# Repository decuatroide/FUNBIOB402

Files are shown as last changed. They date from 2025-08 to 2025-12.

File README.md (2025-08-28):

# Fundamentos de Biodiseño – Grupo 09 
<p align="center">
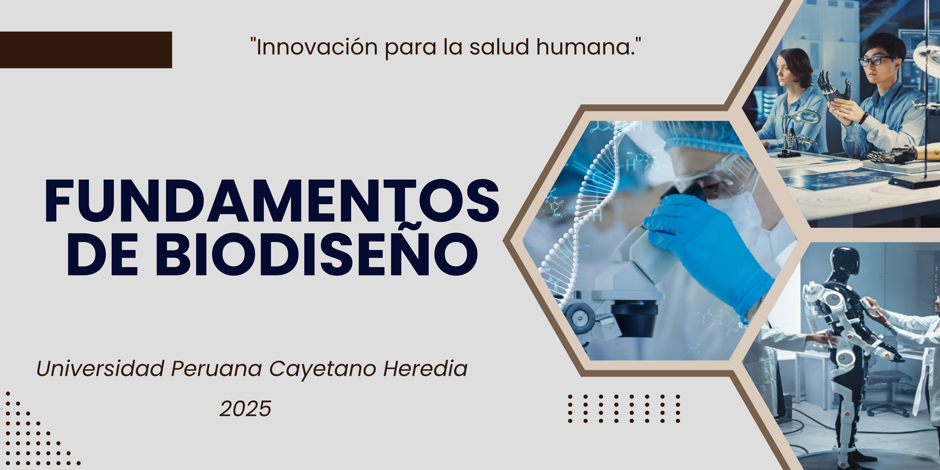
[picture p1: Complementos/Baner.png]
Banner Grupo 09
  
</p>

<p align="center">
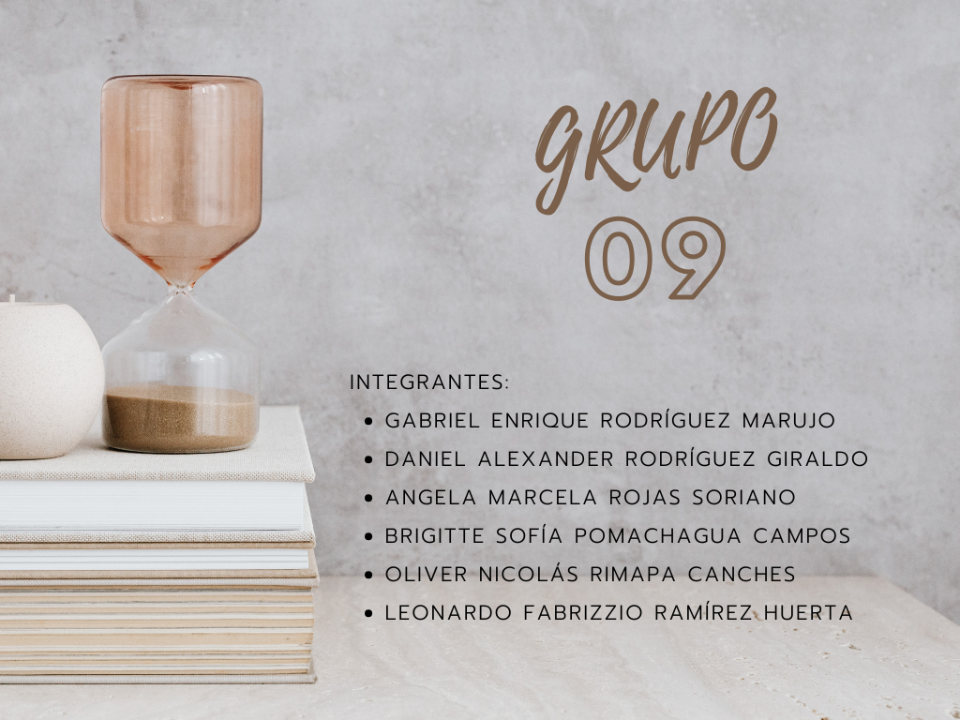
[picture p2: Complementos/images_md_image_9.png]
Carátula del grupo
  
</p>

📸 **Foto de Grupo** 
<p align="center">
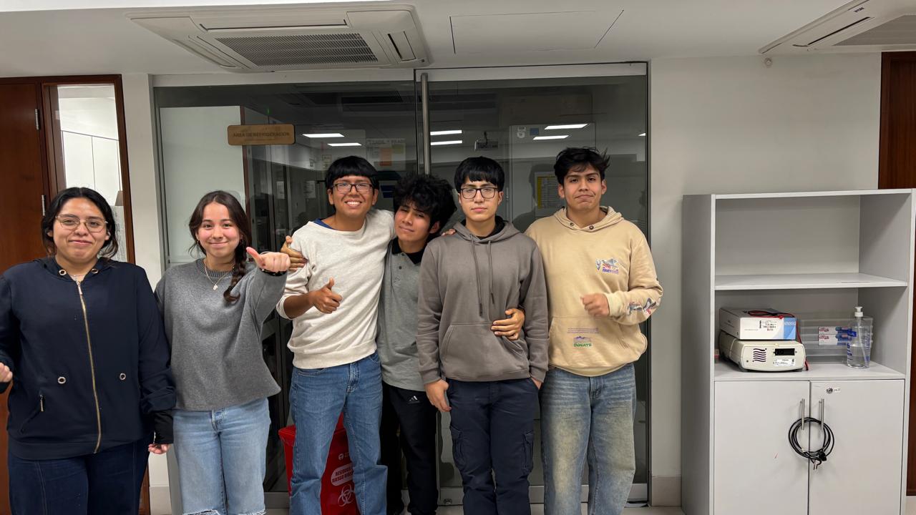
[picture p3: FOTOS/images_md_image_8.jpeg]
Foto de grupo
  
</p>

👩‍🔬**Sobre nosotros**

Somos el Grupo 09 de Fundamentos de Biodiseño, conformado por estudiantes universitarios comprometidos con el aprendizaje y la innovación.  

> 🎯 **Misión:** Integrar los conocimientos de ciencias básicas y diseño con una mirada **creativa y crítica**.  
> 🌍 **Visión:** Proponer **soluciones sostenibles** a los retos que enfrenta la salud y la sociedad actual.  
> 💡 **Objetivo:** Aprender, aplicar y **crear impacto real** mediante el biodiseño.

📚 **Durante el curso buscamos** 

- 🧠 *Adquirir bases teóricas sólidas* .  
- 🤝 *Desarrollar habilidades de trabajo en equipo, análisis y aplicación práctica*.  
- 🚀 *Formarnos como profesionales preparados para afrontar los futuros desafíos de la ingeniería biomédica** .
  
👥 **Integrantes**   
</div>
<table>
  <tr>
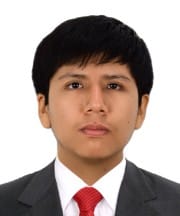
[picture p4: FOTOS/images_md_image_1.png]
    <td width="150px"></td>
    <td>
      <b>Gabriel Enrique Rodríguez Marujo</b>  
      <br>Edad: 18 años  
      <br>🏀 Hábito: Jugar básquet  
      <br><i>"Espero aprender a analizar diferentes tipos de problemáticas y emplear nuevas metodologías y herramientas para llegar a una solución."</i>  
      <br><b>Rol:</b> <font color="blue">Lider </font>
    </td>
  </tr>
</table>

---

<table>
  <tr>
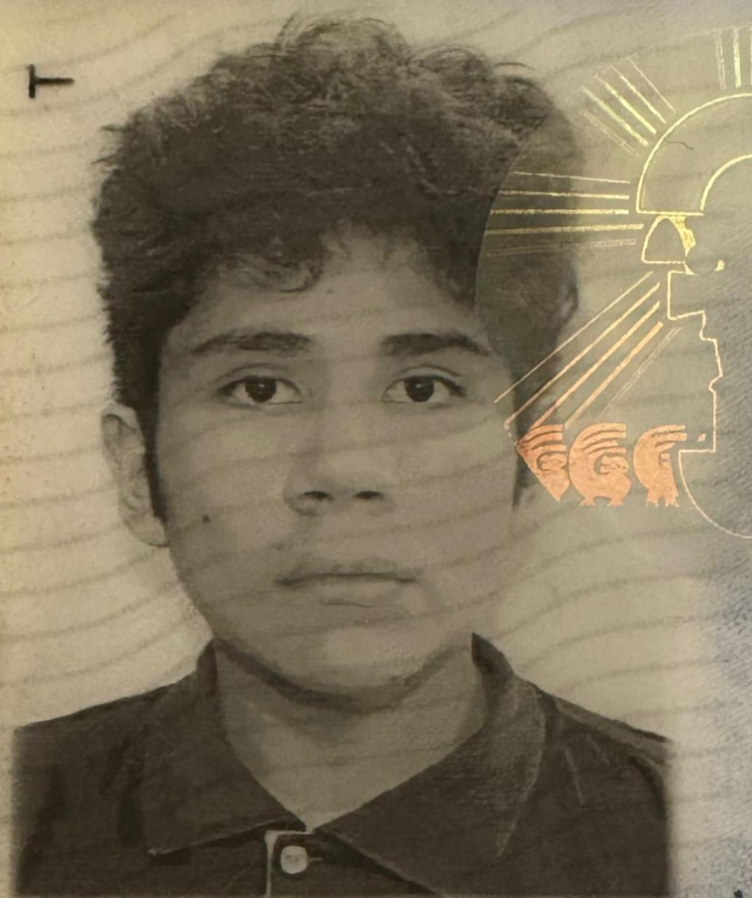
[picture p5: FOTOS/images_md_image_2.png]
    <td width="150px"></td>
    <td>
      <b>Daniel Alexander Rodríguez Giraldo</b>  
      <br>Edad: 19 años  
      <br>🤝 Hábito: Jugar con mis amigos  
      <br><i>"Espero poder aprender mucho en este curso ya que es afín a nuestra carrera."</i>  
      <br><b>Rol:</b> <font color="green">Secretario</font>
    </td>
  </tr>
</table>

---

<table>
  <tr>
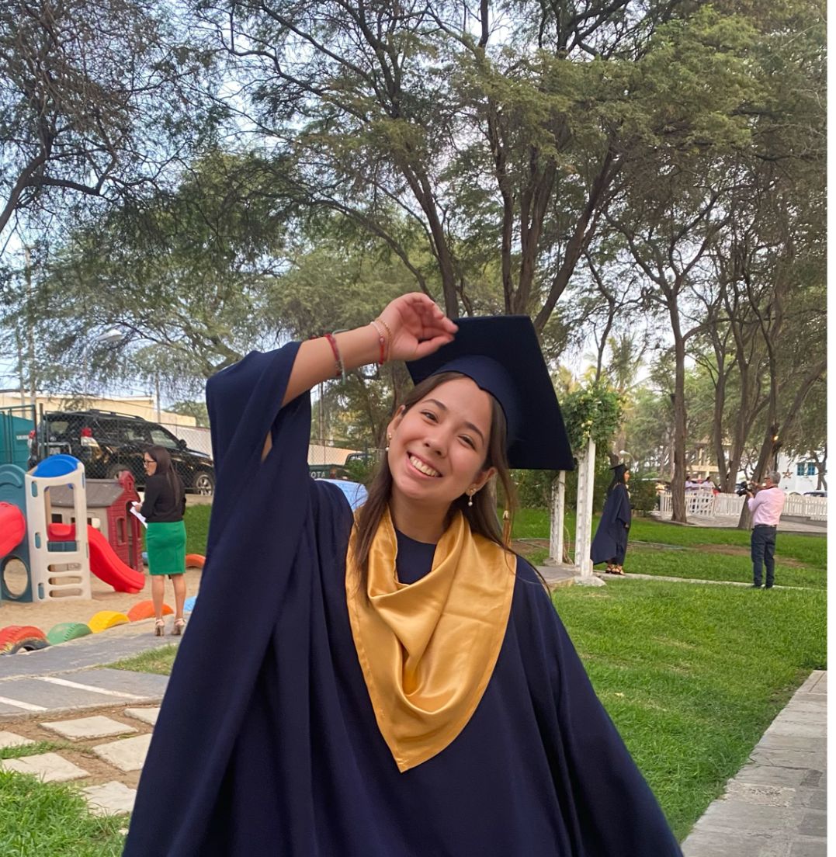
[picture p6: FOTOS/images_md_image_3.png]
    <td width="150px"></td>
    <td>
      <b>Angela Marcela Rojas Soriano</b>  
      <br>Edad: 18 años  
      <br>✈️📸 Hábito: Viajar y tomar fotos  
      <br><i>"Espero aprovechar al máximo las herramientas que este curso ofrece para usarlas en el futuro de mi desarrollo profesional como ingeniera biomédica."</i>  
      <br><b>Rol:</b> <font color="purple">Diseño</font>
    </td>
  </tr>
</table>

---

<table>
  <tr>
    <td width="150px"></td>
    <td>
      <b>Brigitte Sofía Pomachagua Campos</b>  
      <br>Edad: 18 años  
      <br>🎬🍿 Hábito: Ver series y películas  
      <br><i>"Deseo adquirir experiencia en biodiseño para futuros proyectos profesionales."</i>  
      <br><b>Rol:</b> <font color="red">Documentación</font>
    </td>
  </tr>
</table>

---

<table>
  <tr>
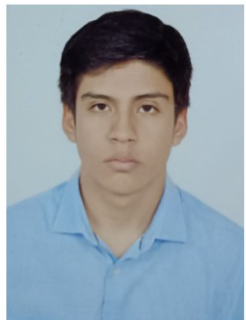
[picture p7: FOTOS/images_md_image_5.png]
    <td width="150px"></td>
    <td>
      <b>Oliver Nicolás Rimapa Canches</b>  
      <br>Edad: 18 años  
      <br>📚📖 Hábito: Leer libros e historietas  
      <br><i>"Espero aportar ideas innovadoras y aprender de mis compañeros."</i>  
      <br><b>Rol:</b> <font color="orange">Organización</font>
    </td>
  </tr>
</table>

---

<table>
  <tr>
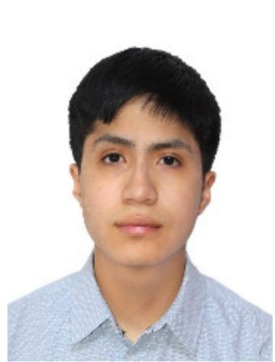
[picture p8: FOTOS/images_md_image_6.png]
    <td width="150px"></td>
    <td>
      <b>Leonardo Fabrizzio Ramírez Huerta</b>  
      <br>Edad: 18 años  
      <br>🎨 Hábito: Dibujo  
      <br><i>"Deseo adquirir experiencia en biodiseño para futuros proyectos profesionales."</i>  
      <br><b>Rol:</b> <font color="brown">Logistica</font>
    </td>
  </tr>
</table>

✨ **Compromiso del Grupo** 

*Estamos convencidos de que la innovación nace del trabajo colaborativo.*  
*Nuestro reto es diseñar soluciones creativas que mejoren la salud y la calidad de vida.* 

*Grupo 09 – Fundamentos de Biodiseño*        📍 *Universidad Peruana Cayetano Heredia – 2025*

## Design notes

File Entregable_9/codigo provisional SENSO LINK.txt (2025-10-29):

// === Pines sensores ===
#define TRIG_FRONT  4
#define ECHO_FRONT  5
#define TRIG_BACK   18
#define ECHO_BACK   19
#define TRIG_LEFT   21
#define ECHO_LEFT   22
#define TRIG_RIGHT  25
#define ECHO_RIGHT  26

// === Pin del módulo de vibración (elige un GPIO de salida) ===
#define PIN_VIB     23   // cambia a tu GPIO "MODVIB" real (evita 34–39)

// === Constantes ===
#define SOUND_SPEED   0.034   // cm/us
#define OBSTACLE_LIMIT 20     // cm
#define INTER_PING_MS  70     // separación entre sensores para evitar diafonía

float medirDistancia(int trigPin, int echoPin) {
  digitalWrite(trigPin, LOW);
  delayMicroseconds(2);
  digitalWrite(trigPin, HIGH);
  delayMicroseconds(10);
  digitalWrite(trigPin, LOW);

  long duracion = pulseIn(echoPin, HIGH, 30000); // 30 ms
  if (duracion == 0) return 400.0;               // timeout => fuera de rango
  float distancia = duracion * SOUND_SPEED * 0.5;
  if (distancia > 400) distancia = 400;
  return distancia;
}

void setup() {
  Serial.begin(115200);

  pinMode(TRIG_FRONT, OUTPUT);  pinMode(ECHO_FRONT, INPUT);
  pinMode(TRIG_BACK,  OUTPUT);  pinMode(ECHO_BACK,  INPUT);
  pinMode(TRIG_LEFT,  OUTPUT);  pinMode(ECHO_LEFT,  INPUT);
  pinMode(TRIG_RIGHT, OUTPUT);  pinMode(ECHO_RIGHT, INPUT);

  pinMode(PIN_VIB, OUTPUT);
  digitalWrite(PIN_VIB, LOW);

  Serial.println("=== Sistema de detección de obstáculos iniciado ===");
}

void loop() {
  float dFront = medirDistancia(TRIG_FRONT, ECHO_FRONT);
  delay(INTER_PING_MS);
  float dBack  = medirDistancia(TRIG_BACK,  ECHO_BACK);
  delay(INTER_PING_MS);
  float dLeft  = medirDistancia(TRIG_LEFT,  ECHO_LEFT);
  delay(INTER_PING_MS);
  float dRight = medirDistancia(TRIG_RIGHT, ECHO_RIGHT);

  Serial.println("------ Lecturas de sensores (cm) ------");
  Serial.print("Frente: ");   Serial.print(dFront); Serial.print(" cm\t");
  Serial.print("Atras: ");    Serial.print(dBack);  Serial.println(" cm");
  Serial.print("Izquierda: ");Serial.print(dLeft);  Serial.print(" cm\t");
  Serial.print("Derecha: ");  Serial.print(dRight); Serial.println(" cm");
  Serial.println("---------------------------------------");

  bool peligro = (dFront < OBSTACLE_LIMIT) || (dBack < OBSTACLE_LIMIT) ||
                 (dLeft  < OBSTACLE_LIMIT) || (dRight< OBSTACLE_LIMIT);

  // Alerta (ON/OFF simple). Si tu driver admite PWM, puedo pasarlo a ledc.
  digitalWrite(PIN_VIB, peligro ? HIGH : LOW);

  if (dFront < OBSTACLE_LIMIT)  Serial.println("⚠  Obstáculo al FRENTE");
  if (dBack  < OBSTACLE_LIMIT)  Serial.println("⚠  Obstáculo ATRÁS");
  if (dLeft  < OBSTACLE_LIMIT)  Serial.println("⚠  Obstáculo a la IZQUIERDA");
  if (dRight < OBSTACLE_LIMIT)  Serial.println("⚠  Obstáculo a la DERECHA");
  if (!peligro)                 Serial.println("✅  Zona despejada.");

  Serial.println();
  delay(200);
}

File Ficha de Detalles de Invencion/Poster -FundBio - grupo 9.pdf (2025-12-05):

# SENSO LINK - SISTEMA INTEGRADO DE BASTÓN CON SENSORES Y APLICACIÓN PARA PERSONA CON SÍNDROME DE CHARGE CON PROBLEMAS SENSORIALES

## Analisis del caso/problematica

## Requerimientos de diseño

## Diseño/Prototipado

## Conclusiones y recomendaciones

### Daniel Rodriguez, Leonardo Ramirez, Oliver Rimapa y Gabriel Rodriguez Marujo

1

### Fundamentos de Biodiseño 2025-2, Ingeniería Biomedica, Facultad de Ciencias e Ingenieria

Paciente:

Piero Franco Zapata, varón de 23 años, diagnosticado con Síndrome CHARGE, una enfermedad genética multisistémica de baja prevalencia (≈1:10000 nacidos vivos), asociada principalmente a mutaciones del gen CHD7 localizado en el cromosoma 8q12.2. [1]

Diagnóstico:

- Síndrome CHARGE: colobomas oculares bilaterales, ceguera total (OI) y baja visión (OD).
- Hipoacusia neurosensorial bilateral: (moderada OD, severa OI).
- Cirugía de escoliosis dorsolumbar (D3–L4): rigidez postural y fatiga.
- Déficit vestibular: dificultad de equilibrio.
- Estado actual: clínicamente estable, pero con dependencia sensorial y emocional al desplazarse solo.

Principal frustración: “No puedo ver correctamente”.

[1] National Eye Institute (NEI), “Coloboma,” National Institutes of Health, Bethesda, MD, 2025. [Online]. Available: https://www.nei.nih.gov/espanol/aprenda-sobre-la-salud-ocular/enfermedades-y-afecciones-de-los-ojos/coloboma.
[2] Google Images, “Hipoacusia neurosensorial bilateral,” Google LLC, Mountain View, CA, 2025. [Online]. Available: https://www.google.com/search?q=hipoacusia+neurosensorial+bilateral+imagen.
[3] Top Doctors, “Déficit vestibular – Reeducación vestibular,” Top Doctors SL, Spain, 2025. [Online]. Available: https://www.topdoctors.es/articulos-medicos/la-reeducacion-vestibular-vertigo-e-inestabilidad/.

[4]World Health Organization (WHO), “Blindness and Visual Impairment – Fact Sheet,” World Health Organization, Geneva, 2024. [Online]. Available: https://www.who.int/es/news-room/fact-sheets/detail/blindness-and-visual-impairment

[5]Consejo Nacional para la Integración de la Persona con Discapacidad (CONADIS), “Se registran 801 mil personas con discapacidad visual en todo el Perú,” Gobierno del Perú, 2024. [Online]. Available: https://www.gob.pe/institucion/conadis/noticias/22052-se-registran-801-mil-personas-con-discapacidad-visual-en-todo-el-peru

## Objetivos

## Resultados y Discusión

## EQUIPO 9 / B-402

Necesidad identificada: “Falta de capacidad sensorial para realizar actividades cotidianas fuera de casa, especialmente derivada de su discapacidad visual y auditiva combinada.”

Objetivo: Diseñar un prototipo que se adapte a las herramientas que ya usa (bastón) para que se sienta más seguro al momento de desplazarse por la calle y su universidad.

Funcionales (F):

1. Detección de obstáculos en rango cercano (0.2 m a 3 m).
2. Retroalimentación háptica direccional según proximidad/dirección del obstáculo.
3. Sincronización | bastón–sistema | integrado | - | App: | mediante
comunicación inalámbrica (p. ej. Bluetooth).
4. Modo bajo consumo de energía para prolongar autonomía.
5. Calibración del usuario (ajuste de sensibilidad, zonas de vibración).

No funcionales (NF):

1. Peso máximo: < 500 g adicionales (bastón + sistema integrado).
2. Tiempo de respuesta: latencia < 100 ms.
3. Durabilidad: resistente a impactos leves, uso diario.
4. Facilidad de uso: interfaz mínima, intuitiva.
5. Costo objetivo: menor que tecnologías altas (e.g. < US$ 500).

Solución: SENSO-LINK

Sistema de navegación táctil con sensores ultrasónicos integrados al bastón.

¿Cómo funciona?

- Usa 4 sensores, el primera con dirección hacia abajo el cual mide la distancia de SENSO-LINK al suelo y esta medida, activa a los otros sensores(1 frontal,2 laterales) para que detecten los obstáculos)
- La información se procesa en tiempo real con un microcontrolador.
- Un módulo vibrador alerta a Piero con patrones táctiles intuitivos según la dirección del obstáculo.

Pasos:

1.- Hardware: (Componentes electrónicos) 2.- Software: (Aplicación - Botón de pánico)

3.- Manufactura Digital: (Case)

4.- | Ensamblado:

Limitaciónes:

}

Posibles Mejoras:
- Sensores de mayor área
- Case adaptable a diferentes tamaños
- Mayor duración de la batería
- Aplicación sin restricción a la hora de enviar SMS
- Boton de mayor presencia
- Case más compacto y estético

En conclusión, nuestro prototipo tiene bien definido el objetivo de ser un sistema integrado que se pueda adaptar a cualquier tipo de bastón para personas con problemas sensoriales similares a nuestro caso clínico debido a su bajo peso, poco espacio y que aprovecha las herramientas de los pacientes para cumplir su función. Sin embargo, aún tiene fuertes limitaciones que pueden ser resueltas que comprometen a los objetivos principales con un poco más de presupuesto y tiempo para que pueda llegar a ser totalmente funcional.

1er Case
2do Case
Duración de la batería | Entre 2 a 3h vibrando constantemente y unas 4 si no llega a detectar nada por grandes periodos de tiempo
Visión limitada | Por el mismo planteamiento solo compara el terreno en 3 direcciones, a futuro con sensores de mayor rango se espera poder abarcar un mayor rango
El botón de emergencia aún requiere participación del paciente | El SMS aún no se envia automaticamente
Aún ocupa mucho espacio | Por el planteamiento actual del proyecto no es posible reducir su tamaño pero se espera volverlo un aditamento discreto para cualquier bastón

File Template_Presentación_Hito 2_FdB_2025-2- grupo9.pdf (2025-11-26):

# Indicaciones

- Este template es un esquema base para la construcción de su Elevator Pitch en base a los entregables del curso.
- Se recomienda hacer una presentación con alto contenido visual, enfocada en presentar ideas centrales en un Pitch de 7 minutos.
- El diseño estético de la carátula y de las demás diapositivas queda a criterio del alumno. El orden y contenido indicado en cada slide es obligatorio.

# - Se recomienda ceñirse al número de slides del template, para utilizar aproximadamente 1

min/diapositiva y culminar en el tiempo asignado. Sean precisos y claros en su discurso.
- El slide para la demo está fuera de los 7 min y puede durar 2:00 min máx. Los slides extra son para información de soporte durante las preguntas de los asesores respecto a los retos y limitaciones de sus prototipos.
- Asistir con vestimenta formal para la presentación del Hito N° 2.

# ¡Éxitos en su presentación!

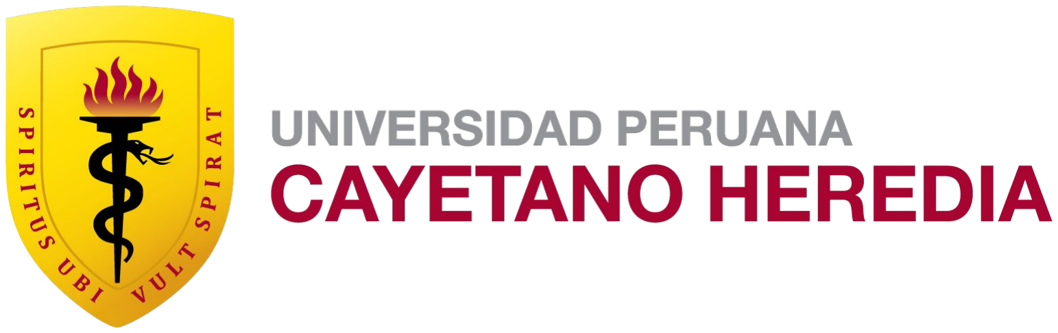
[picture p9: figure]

# SENSO-LINK

# SENSO-LINK

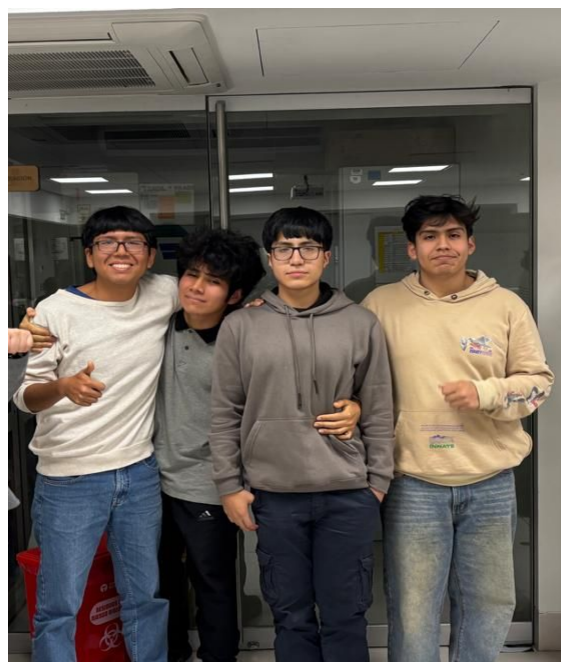
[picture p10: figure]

# Integrantes del grupo 9: - Daniel Alexander Rodríguez Giraldo - Oliver Nicolás Rimapa Canches - Leonardo Fabrizzio Ramírez Huerta - Gabriel Enrique Rodriguez Marujo

# - Leonardo Fabrizzio Ramírez Huerta - Gabriel Enrique Rodriguez Marujo

# Problemática

# Paciente: Piero Franco Zapata diagnosticado con

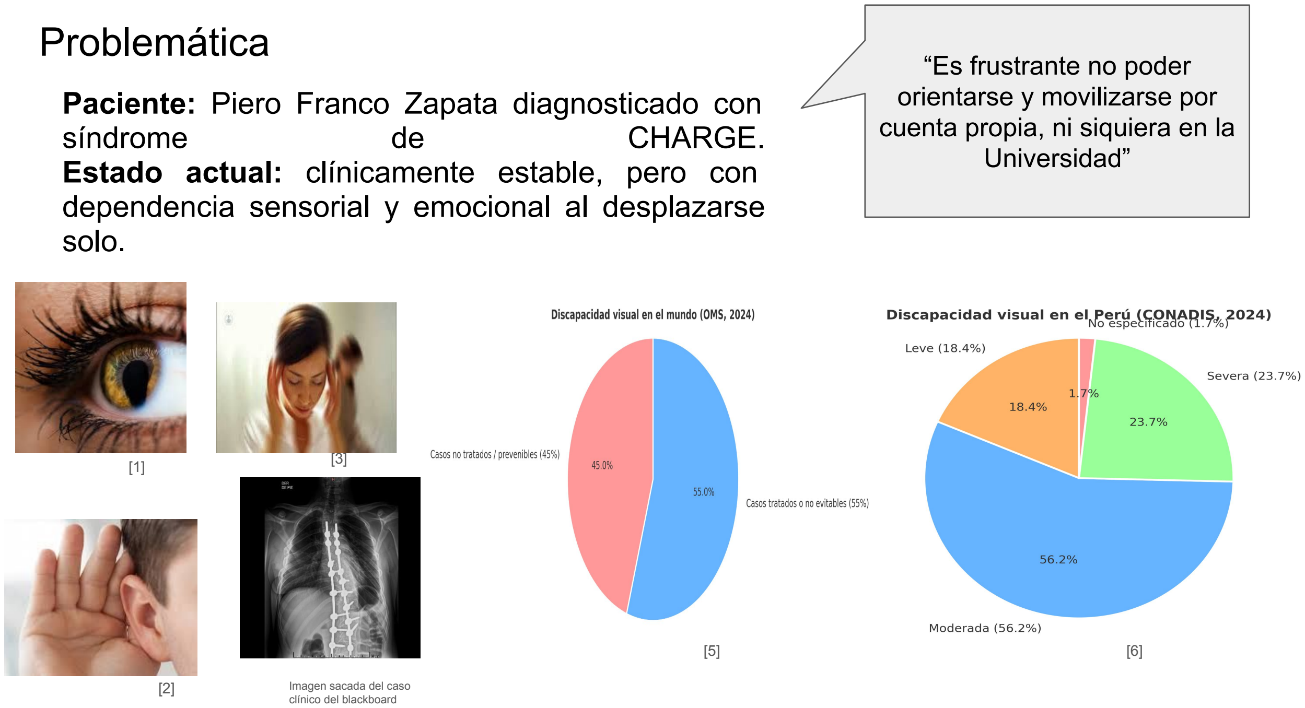
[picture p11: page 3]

síndrome | de | CHARGE.

# Estado actual: clínicamente estable, pero con dependencia sensorial y emocional al desplazarse

solo.

# “Es frustrante no poder orientarse y movilizarse por cuenta propia, ni siquiera en la Universidad”

Imagen sacada del caso
clínico del blackboard

[1]

[2]

[3]

[5] [6]

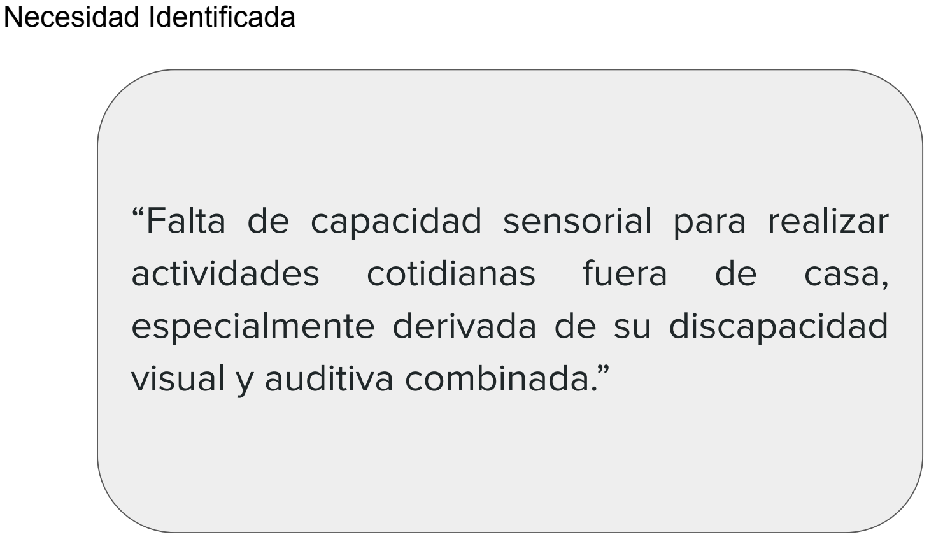
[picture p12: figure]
actividades; cotidianas; fuera; casa,; visual y auditiva combinada.”; Necesidad Identificada

# “Falta de capacidad sensorial para realizar

# especialmente derivada de su discapacidad

# Estado del Arte: Inspiraciones tecnológicas para nuestro prototipo

Patente | Dispositivo | Aporte clave | Aplicación
US12133582B1 [6] | Gafas hápticas | Sistema multisensorial para identificar obstáculos cercanos | Referencia para optimizar la lectura y activación de los sensores ultrasónicos
US20210369545A1 [7] | Bastón inteligente | Algoritmo que combina datos de sensores para alertas más precisas | Inspiración para mejorar la precisión de detección del bastón.
WO2022131891A1 [8] | Bastón háptico | Emisión de vibración. | Referente para implementar vibraciones direccionales en el bastón
US10900788B2 [9] | Cinturón sensorial | Activación de una señal de emergencia según activación del usuario. | Inspiración para el botón de pánico que envía SMS a un familiar cercano

# Solución

# SENSO-LINK

Sistema de navegación táctil con sensores ultrasónicos integrados al bastón.

# ¿Cómo funciona? (3 pasos)

- Usa 4 sensores, el primera con dirección hacia abajo el cual mide la distancia de SENSO-LINK al suelo y esta medida, activa a

## los otros sensores(1 frontal,2 laterales) para que detecten los obstaculos)

- La información se procesa en tiempo real con un microcontrolador.
- Un módulo vibrador alerta a Piero con patrones táctiles intuitivos según la dirección del obstáculo.

# Esquema Electrónico - SENSO LINK Elaborado en EasyEDA [11]

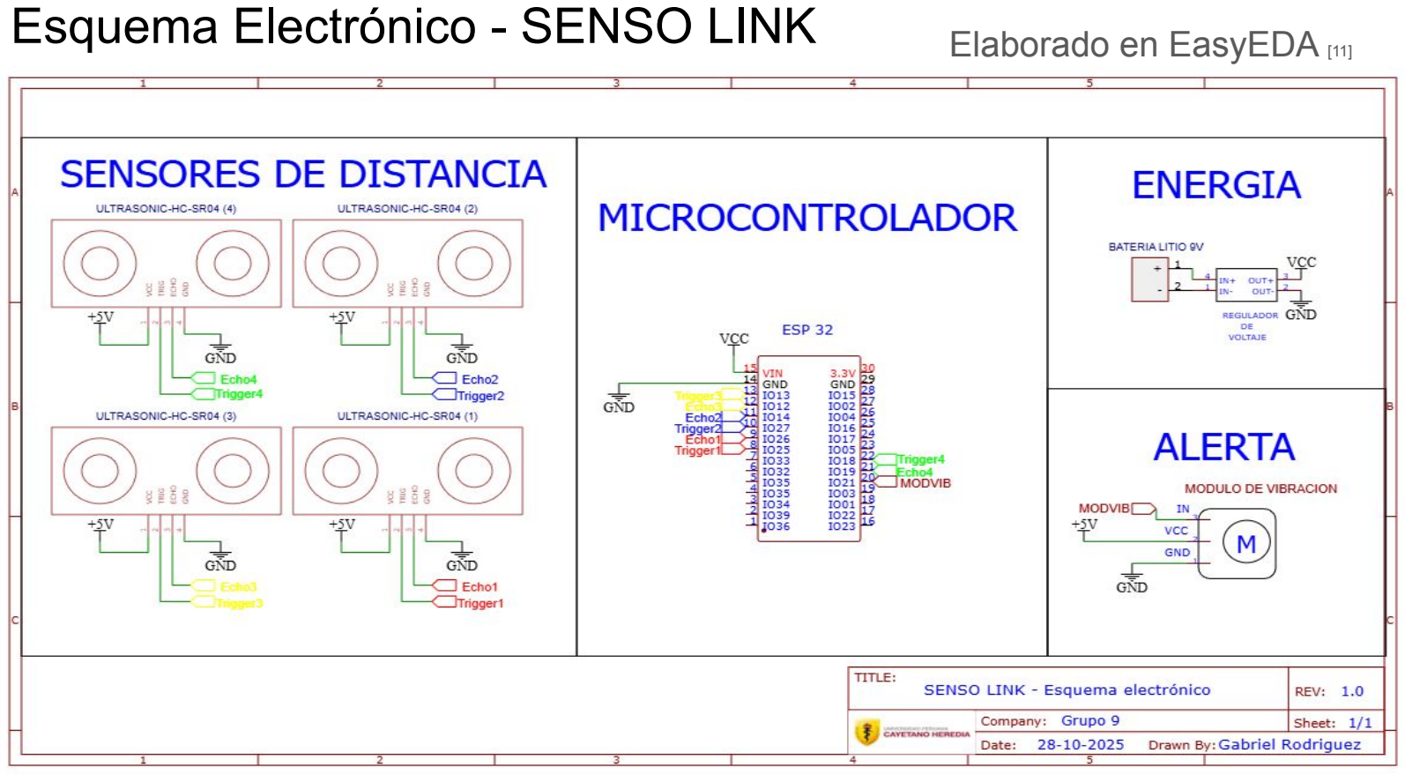
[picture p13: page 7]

# Botón de Pánico: Aplicación en APP Inventor

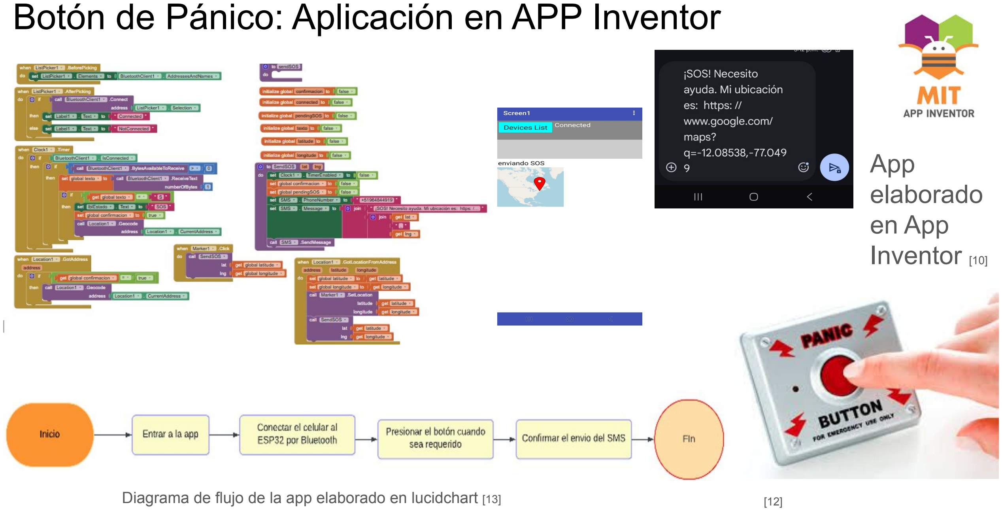
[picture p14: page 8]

# App elaborado en App Inventor [10]

Diagrama de flujo de la app elaborado en lucidchart | [12] [13]

# Tracción

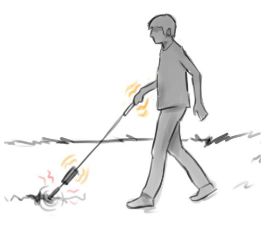
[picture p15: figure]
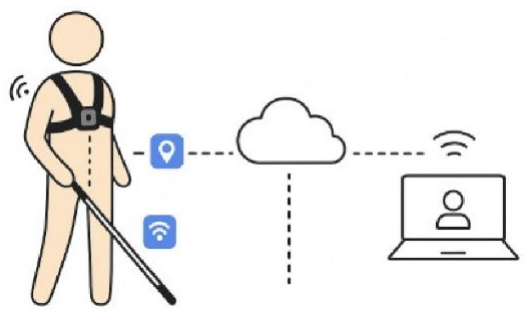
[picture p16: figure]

# Tracción

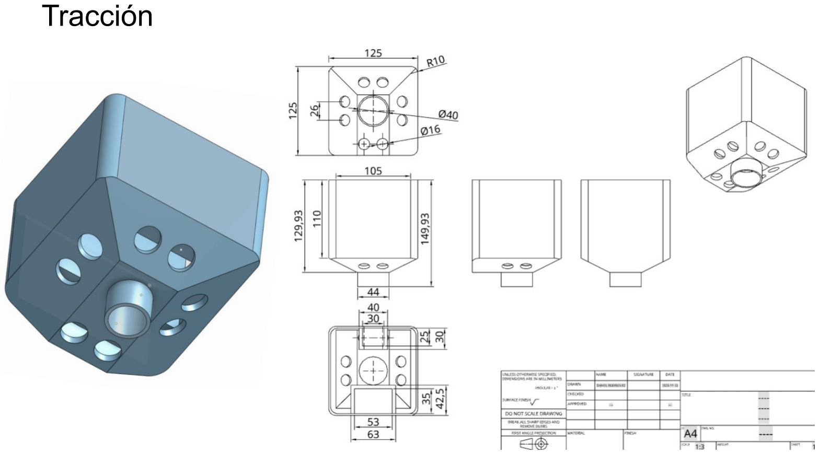
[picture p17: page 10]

# Tracción

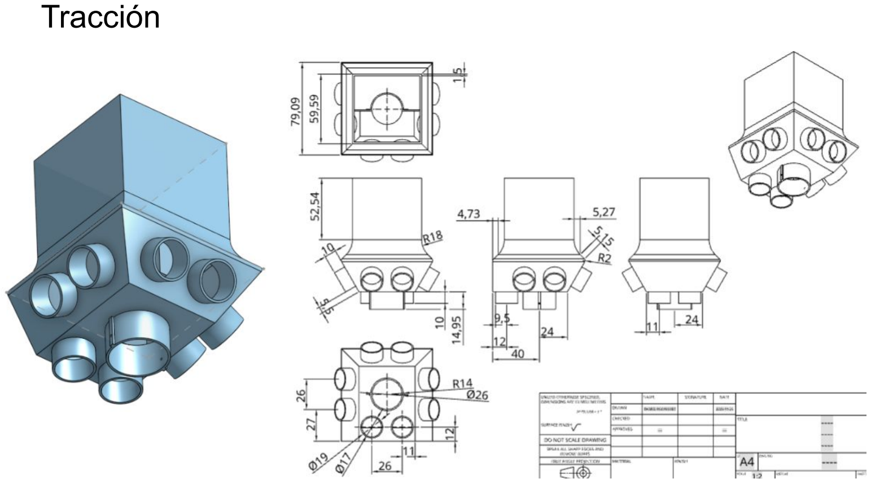
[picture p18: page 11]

# Tracción

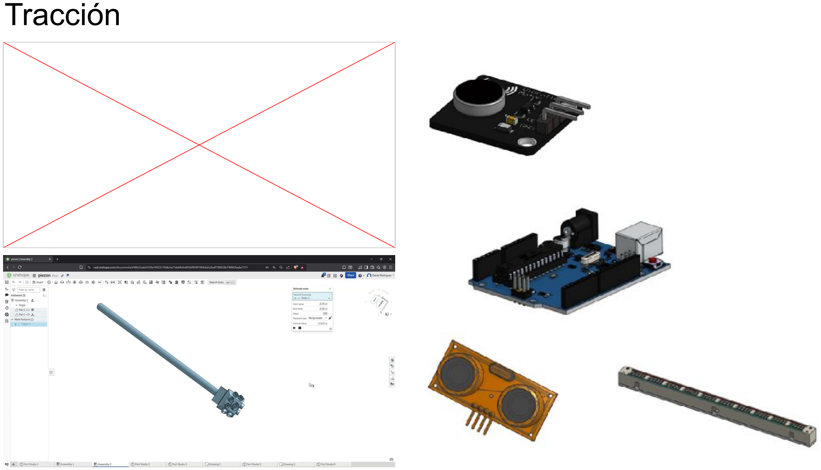
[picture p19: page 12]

# Tracción

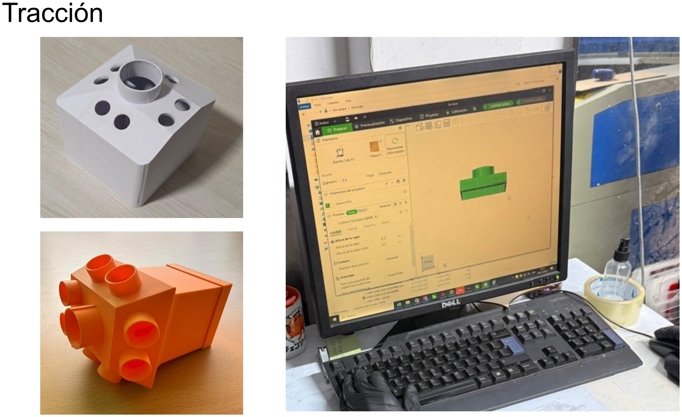
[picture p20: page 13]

# Tracción Funcionamiento mediante batería y funciones integradas con bluetooth

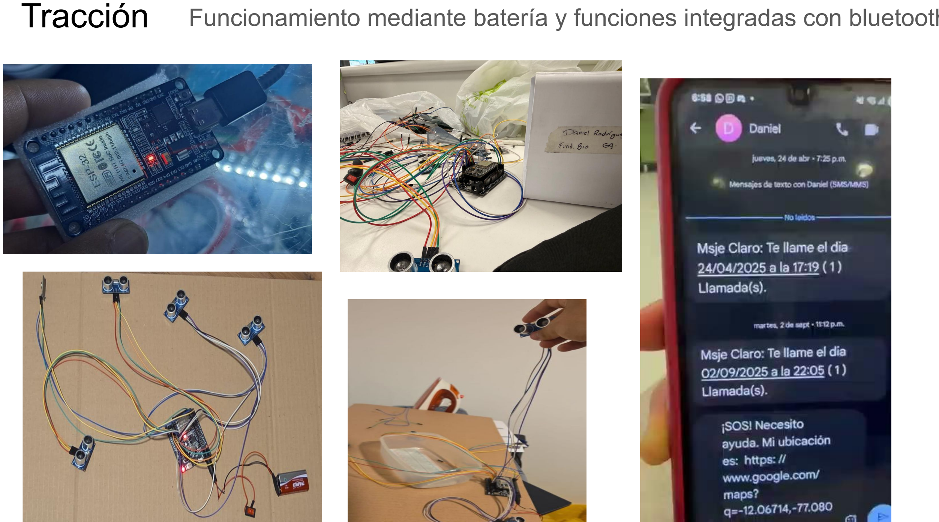
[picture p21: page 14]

# Referencias

[1] National Eye Institute (NEI), “Coloboma,” National Institutes of Health, Bethesda, MD, 2025. [Online]. Available: https://www.nei.nih.gov/espanol/aprenda-sobre-la-salud-ocular/enfermedades-y-afecciones-de-los-ojos/coloboma.
[2] Google Images, “Hipoacusia neurosensorial bilateral,” Google LLC, Mountain View, CA, 2025. [Online]. Available: https://www.google.com/search?q=hipoacusia+neurosensorial+bilateral+imagen.
[3] Top Doctors, “Déficit vestibular – Reeducación vestibular,” Top Doctors SL, Spain, 2025. [Online]. Available: https://www.topdoctors.es/articulos-medicos/la-reeducacion-vestibular-vertigo-e-inestabilidad/.

[4]World Health Organization (WHO), “Blindness and Visual Impairment – Fact Sheet,” World Health Organization, Geneva, 2024. [Online]. Available: https://www.who.int/es/news-room/fact-sheets/detail/blindness-and-visual-impairment

[5]Consejo Nacional para la Integración de la Persona con Discapacidad (CONADIS), “Se registran 801 mil personas con discapacidad visual en todo el Perú,” Gobierno del Perú, 2024. [Online]. Available: https://www.gob.pe/institucion/conadis/noticias/22052-se-registran-801-mil-personas-con-discapacidad-visual-en-todo-el-peru

[6] U.S. Patent US12133582B1, Smart cane for a visually impaired individual, 2024.
[7] U.S. Patent Application US20210369545A1, Method and system for smart navigation for the visually impaired, 2021.
[8] World Intellectual Property Organization, Patent WO2022131891A1, Haptic cane device, 2022.
[9] U.S. Patent US10900788B2, Wearable sensory belt system, 2021.
[10] MIT App Inventor, “MIT App Inventor,” Massachusetts Institute of Technology, Cambridge, MA, 2025. [Online]. Available: https://appinventor.mit.edu/
[11] EasyEDA, “EasyEDA Online Circuit Design,” EasyEDA Inc., 2025. [Online]. Available: https://easyeda.com/
[12] GPSTEC, “Botón de pánico – alerta.jpg,” GPSTEC Argentina, 2015. [Online]. Available: http://www.gpstec.com.ar/wp-content/uploads/2015/04/boton-de-panico-alerta.jpg
[13] Lucidchart, “Lucidchart – Diagramming Application,” Lucid Software Inc., South Jordan, UT, 2025. [Online]. Available: https://www.lucidchart.com/

# Slide extra: Limitaciones

Duración de la batería | Entre 2 a 3h vibrando constantemente y unas 4 si no llega a detectar nada por grandes periodos de tiempo
Visión limitada | por el mismo planteamiento solo compara el terreno en 3 direcciones, a futuro con sensores de mayor rango se espera poder abarcar un mayor rango
El botón de emergencia aún requiere participación del paciente | El SMS aún no se envia automaticamente
Aún ocupa mucho espacio | Por el planteamiento actual del proyecto no es posible reducir su tamaño pero se espera volverlo un aditamento discreto para cualquier baston

# Slide extra: Pruebas y testeos

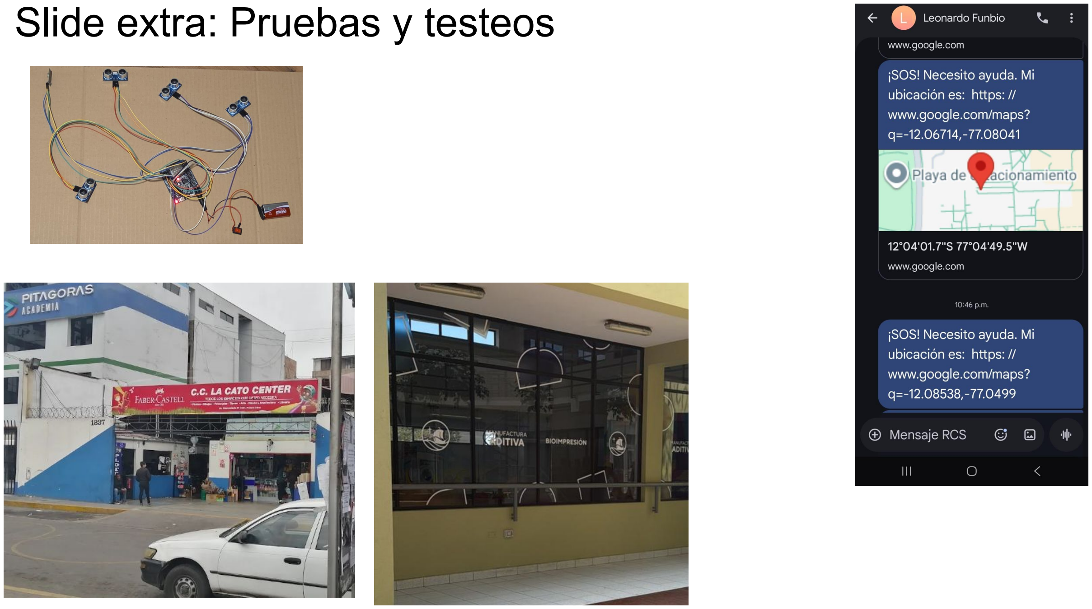
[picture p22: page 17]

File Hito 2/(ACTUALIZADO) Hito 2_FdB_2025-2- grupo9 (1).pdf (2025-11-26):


# SENSO-LINK

# SENSO-LINK


# Integrantes del grupo 9: - Daniel Alexander Rodríguez Giraldo - Oliver Nicolás Rimapa Canches - Leonardo Fabrizzio Ramírez Huerta - Gabriel Enrique Rodriguez Marujo

# - Leonardo Fabrizzio Ramírez Huerta - Gabriel Enrique Rodriguez Marujo

# Problemática

# Paciente: Piero Franco Zapata diagnosticado con


síndrome | de | CHARGE.

# Estado actual: clínicamente estable, pero con dependencia sensorial y emocional al desplazarse

solo.

# “Es frustrante no poder orientarse y movilizarse por cuenta propia, ni siquiera en la Universidad”

Imagen sacada del caso
clínico del blackboard

[1]

[2]

[3]

[5] [6]

actividades; cotidianas; fuera; casa,; visual y auditiva combinada.”; Necesidad Identificada

# “Falta de capacidad sensorial para realizar

# especialmente derivada de su discapacidad

# Estado del Arte: Inspiraciones tecnológicas para nuestro prototipo

Patente | Dispositivo | Aporte clave | Aplicación
US12133582B1 [6] | Gafas hápticas | Sistema multisensorial para identificar obstáculos cercanos | Referencia para optimizar la lectura y activación de los sensores ultrasónicos
US20210369545 A1 [7] | Bastón inteligente | Algoritmo que combina datos de sensores para alertas más precisas | Inspiración para mejorar la precisión de detección del bastón.
WO2022131891 A1 [8] | Bastón háptico | Emisión de vibración. | Referente para implementar vibraciones direccionales en el bastón
US10900788B2 [9] | Cinturón sensorial | Activación de una señal de emergencia según activación del usuario. | Inspiración para el botón de pánico que envía SMS a un familiar cercano

# Solución

# SENSO-LINK

Sistema de navegación táctil con sensores ultrasónicos integrados al bastón.

# ¿Cómo funciona? (3 pasos)

- Usa 4 sensores, el primera con dirección hacia abajo el cual mide la distancia de SENSO-LINK al suelo y esta medida, activa a

## los otros sensores(1 frontal,2 laterales) para que detecten los obstáculos)

- La información se procesa en tiempo real con un microcontrolador.
- Un módulo vibrador alerta a Piero con patrones táctiles intuitivos según la dirección del obstáculo.

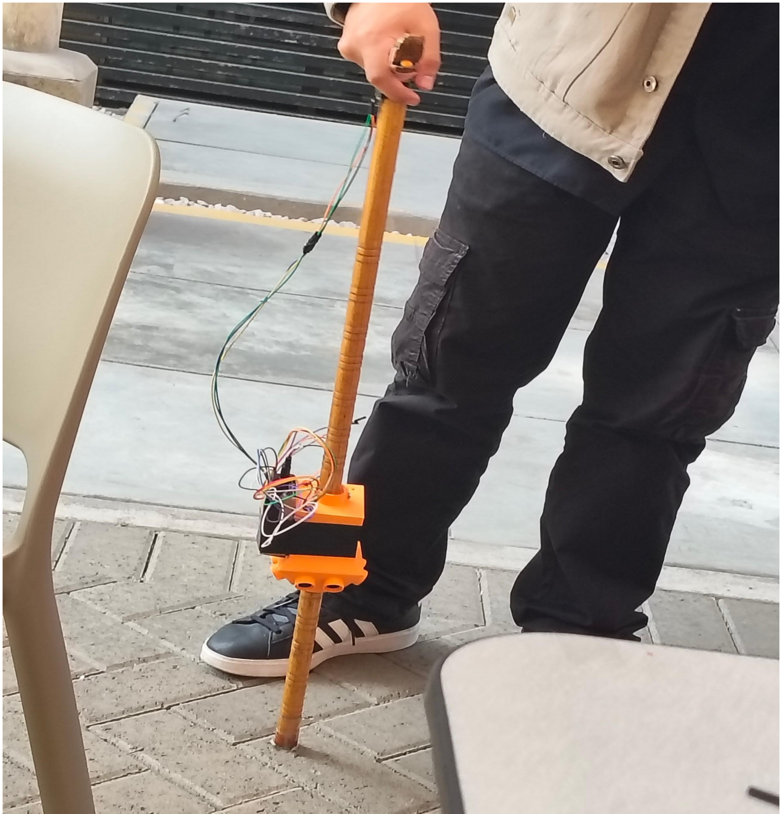
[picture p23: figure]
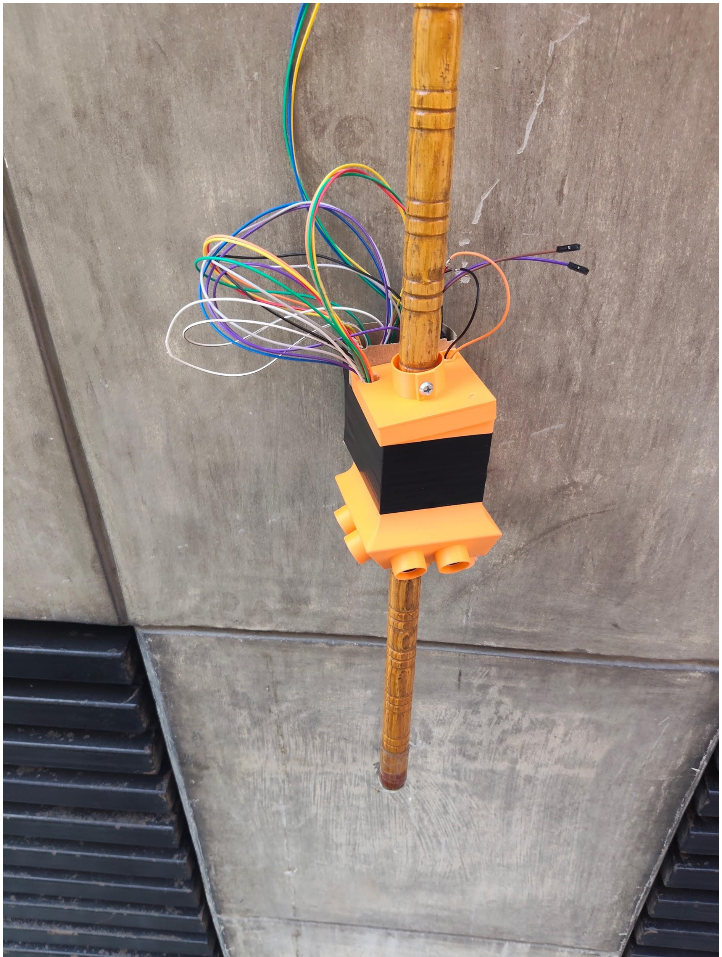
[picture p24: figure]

# Esquema Electrónico - SENSO LINK Elaborado en EasyEDA [11]

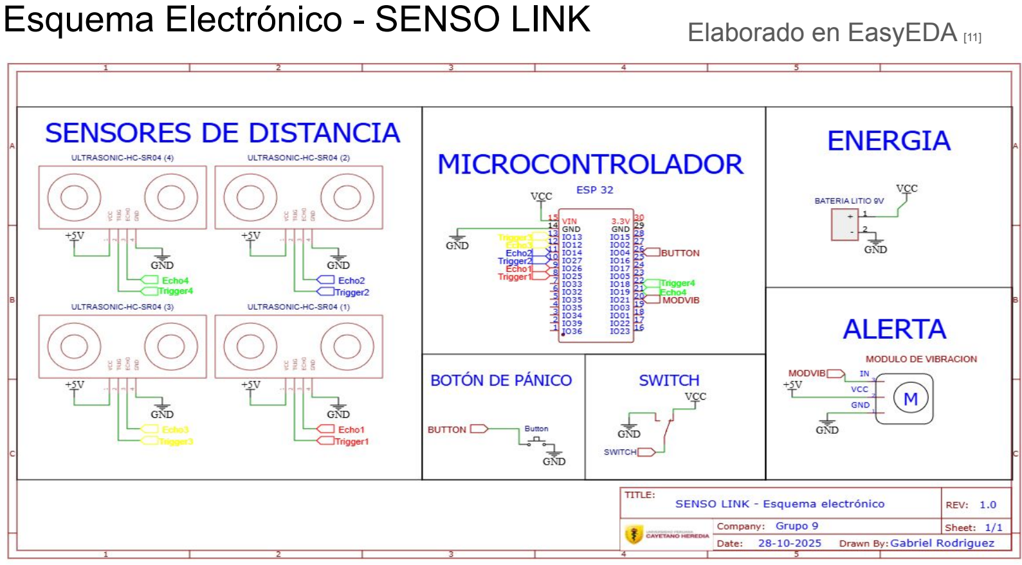
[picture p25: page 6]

# Botón de Pánico: Aplicación en APP Inventor

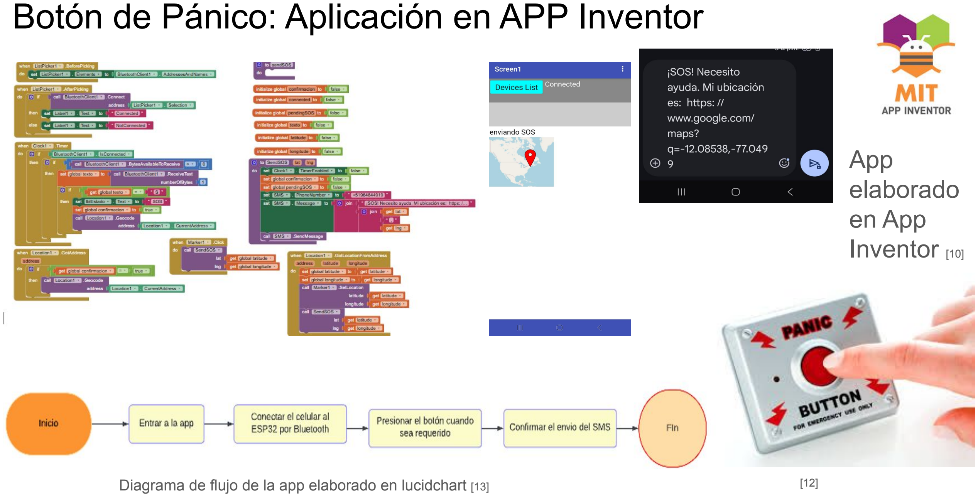
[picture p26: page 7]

# App elaborado en App Inventor [10]

Diagrama de flujo de la app elaborado en lucidchart | [12] [13]

# Tracción- Primeros bocetos

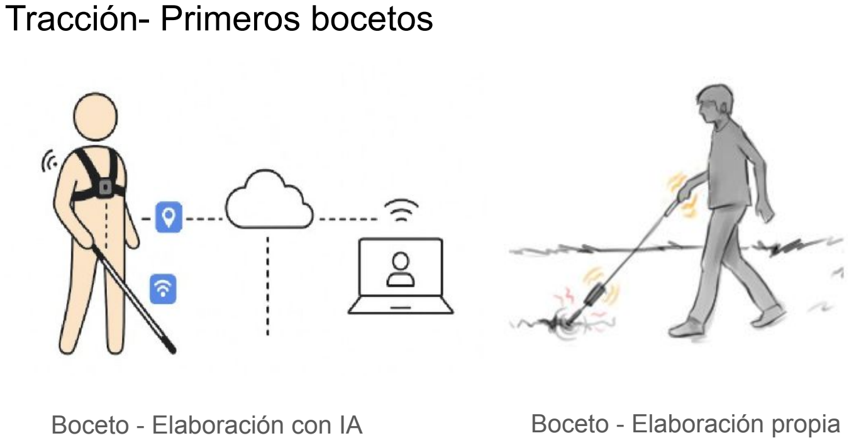
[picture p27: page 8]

Boceto - Elaboración con IA | Boceto - Elaboración propia

# Tracción - elaborado con Onshape

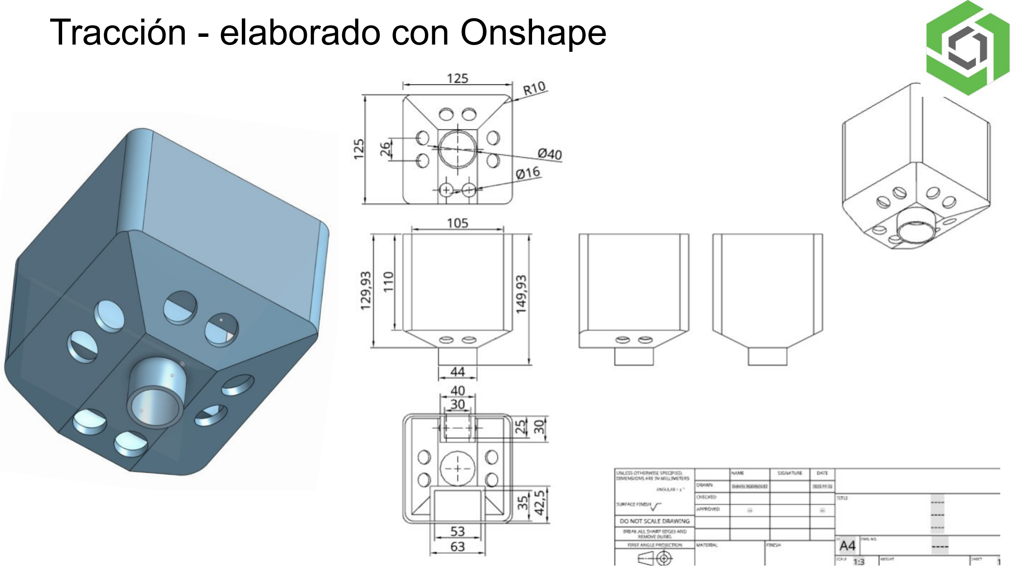
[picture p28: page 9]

# Tracción- Elaborado con Onshape

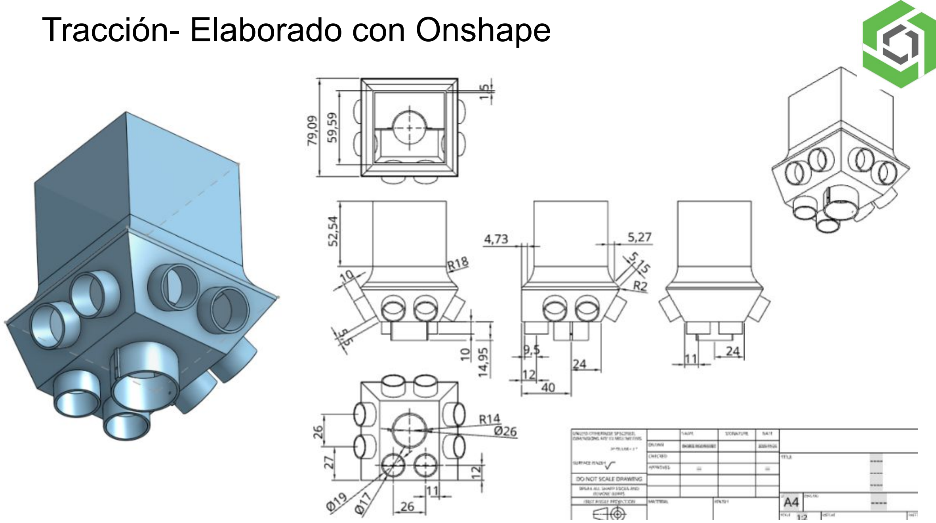
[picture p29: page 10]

# Tracción

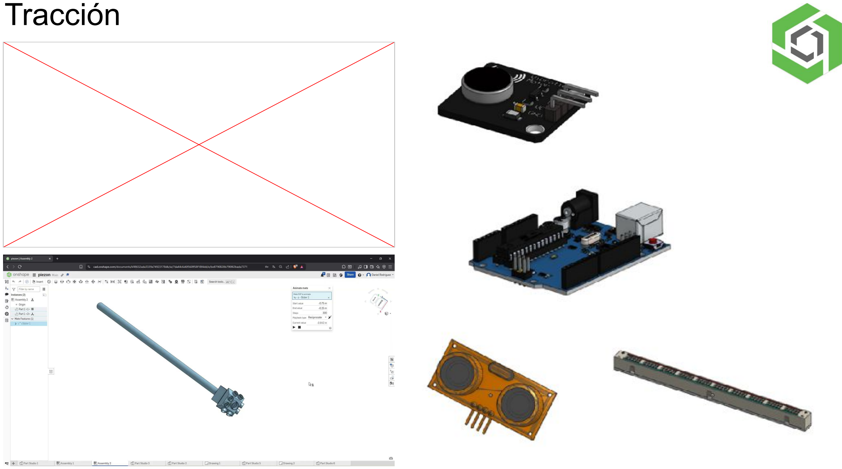
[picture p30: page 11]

# Tracción

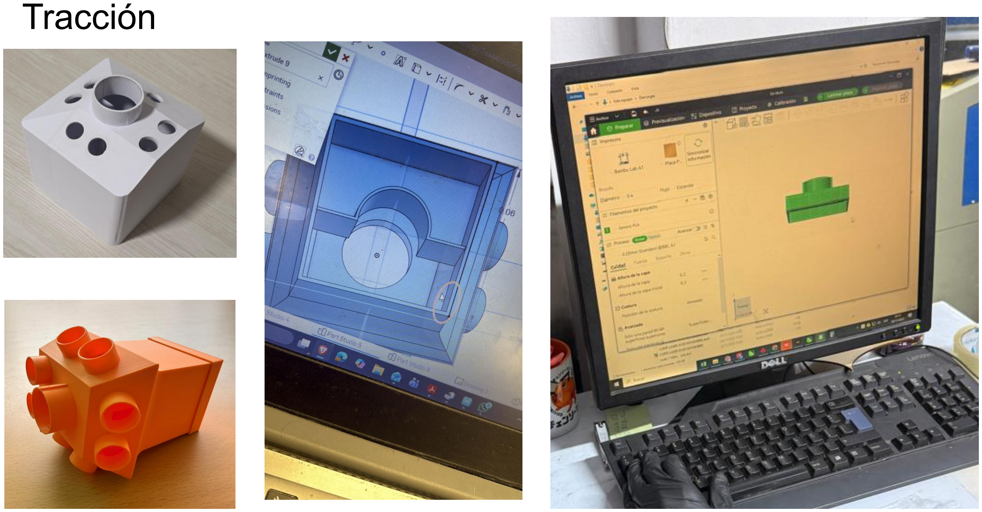
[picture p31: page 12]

# Tracción Funcionamiento mediante batería y funciones integradas con bluetooth

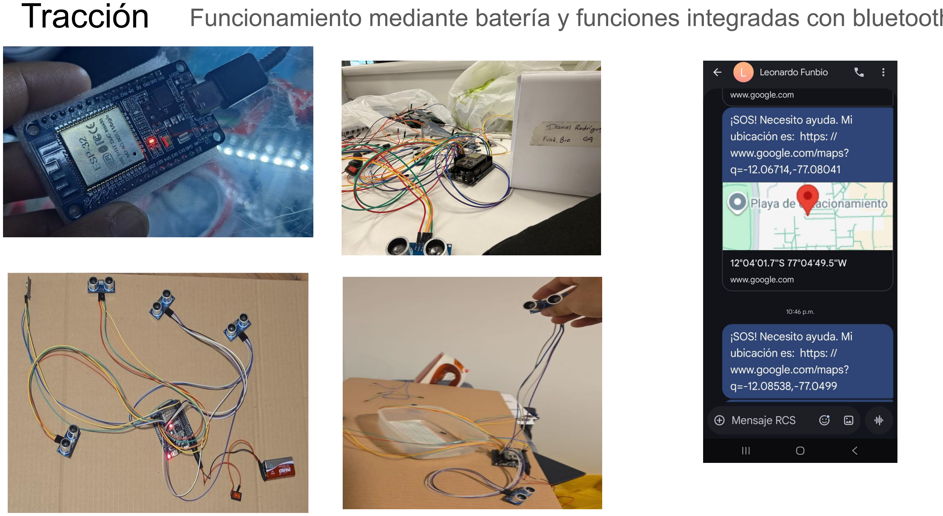
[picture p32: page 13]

# Referencias

[1] National Eye Institute (NEI), “Coloboma,” National Institutes of Health, Bethesda, MD, 2025. [Online]. Available: https://www.nei.nih.gov/espanol/aprenda-sobre-la-salud-ocular/enfermedades-y-afecciones-de-los-ojos/coloboma.
[2] Google Images, “Hipoacusia neurosensorial bilateral,” Google LLC, Mountain View, CA, 2025. [Online]. Available: https://www.google.com/search?q=hipoacusia+neurosensorial+bilateral+imagen.
[3] Top Doctors, “Déficit vestibular – Reeducación vestibular,” Top Doctors SL, Spain, 2025. [Online]. Available: https://www.topdoctors.es/articulos-medicos/la-reeducacion-vestibular-vertigo-e-inestabilidad/.

[4]World Health Organization (WHO), “Blindness and Visual Impairment – Fact Sheet,” World Health Organization, Geneva, 2024. [Online]. Available: https://www.who.int/es/news-room/fact-sheets/detail/blindness-and-visual-impairment

[5]Consejo Nacional para la Integración de la Persona con Discapacidad (CONADIS), “Se registran 801 mil personas con discapacidad visual en todo el Perú,” Gobierno del Perú, 2024. [Online]. Available: https://www.gob.pe/institucion/conadis/noticias/22052-se-registran-801-mil-personas-con-discapacidad-visual-en-todo-el-peru

[6] U.S. Patent US12133582B1, Smart cane for a visually impaired individual, 2024.
[7] U.S. Patent Application US20210369545A1, Method and system for smart navigation for the visually impaired, 2021.
[8] World Intellectual Property Organization, Patent WO2022131891A1, Haptic cane device, 2022.
[9] U.S. Patent US10900788B2, Wearable sensory belt system, 2021.
[10] MIT App Inventor, “MIT App Inventor,” Massachusetts Institute of Technology, Cambridge, MA, 2025. [Online]. Available: https://appinventor.mit.edu/
[11] EasyEDA, “EasyEDA Online Circuit Design,” EasyEDA Inc., 2025. [Online]. Available: https://easyeda.com/
[12] GPSTEC, “Botón de pánico – alerta.jpg,” GPSTEC Argentina, 2015. [Online]. Available: http://www.gpstec.com.ar/wp-content/uploads/2015/04/boton-de-panico-alerta.jpg
[13] Lucidchart, “Lucidchart – Diagramming Application,” Lucid Software Inc., South Jordan, UT, 2025. [Online]. Available: https://www.lucidchart.com/

# Slide extra: Limitaciones

Duración de la batería | Entre 2 a 3h vibrando constantemente y unas 4 si no llega a detectar nada por grandes periodos de tiempo
Visión limitada | por el mismo planteamiento solo compara el terreno en 3 direcciones, a futuro con sensores de mayor rango se espera poder abarcar un mayor rango
El botón de emergencia aún requiere participación del paciente | El SMS aún no se envia automaticamente
Aún ocupa mucho espacio | Por el planteamiento actual del proyecto no es posible reducir su tamaño pero se espera volverlo un aditamento discreto para cualquier baston

# Slide extra: Pruebas y testeos


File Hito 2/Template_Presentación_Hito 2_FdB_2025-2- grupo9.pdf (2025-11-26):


# SENSO-LINK

# SENSO-LINK


# Integrantes del grupo 9: - Daniel Alexander Rodríguez Giraldo - Oliver Nicolás Rimapa Canches - Leonardo Fabrizzio Ramírez Huerta - Gabriel Enrique Rodriguez Marujo

# - Leonardo Fabrizzio Ramírez Huerta - Gabriel Enrique Rodriguez Marujo

# Problemática

# Paciente: Piero Franco Zapata diagnosticado con


síndrome | de | CHARGE.

# Estado actual: clínicamente estable, pero con dependencia sensorial y emocional al desplazarse

solo.

# “Es frustrante no poder orientarse y movilizarse por cuenta propia, ni siquiera en la Universidad”

Imagen sacada del caso
clínico del blackboard

[1]

[2]

[3]

[5] [6]

actividades; cotidianas; fuera; casa,; visual y auditiva combinada.”; Necesidad Identificada

# “Falta de capacidad sensorial para realizar

# especialmente derivada de su discapacidad

# Estado del Arte: Inspiraciones tecnológicas para nuestro prototipo

Patente | Dispositivo | Aporte clave | Aplicación
US12133582B1 [6] | Gafas hápticas | Sistema multisensorial para identificar obstáculos cercanos | Referencia para optimizar la lectura y activación de los sensores ultrasónicos
US20210369545A1 [7] | Bastón inteligente | Algoritmo que combina datos de sensores para alertas más precisas | Inspiración para mejorar la precisión de detección del bastón.
WO2022131891A1 [8] | Bastón háptico | Emisión de vibración. | Referente para implementar vibraciones direccionales en el bastón
US10900788B2 [9] | Cinturón sensorial | Activación de una señal de emergencia según activación del usuario. | Inspiración para el botón de pánico que envía SMS a un familiar cercano

# Solución

# SENSO-LINK

Sistema de navegación táctil con sensores ultrasónicos integrados al bastón.

# ¿Cómo funciona? (3 pasos)

- Usa 4 sensores, el primera con dirección hacia abajo el cual mide la distancia de SENSO-LINK al suelo y esta medida, activa a

## los otros sensores(1 frontal,2 laterales) para que detecten los obstaculos)

- La información se procesa en tiempo real con un microcontrolador.
- Un módulo vibrador alerta a Piero con patrones táctiles intuitivos según la dirección del obstáculo.

# Esquema Electrónico - SENSO LINK Elaborado en EasyEDA [11]


# Botón de Pánico: Aplicación en APP Inventor


# App elaborado en App Inventor [10]

Diagrama de flujo de la app elaborado en lucidchart | [12] [13]

# Tracción


# Tracción


# Tracción


# Tracción


# Tracción


# Tracción Funcionamiento mediante batería y funciones integradas con bluetooth


# Referencias

[1] National Eye Institute (NEI), “Coloboma,” National Institutes of Health, Bethesda, MD, 2025. [Online]. Available: https://www.nei.nih.gov/espanol/aprenda-sobre-la-salud-ocular/enfermedades-y-afecciones-de-los-ojos/coloboma.
[2] Google Images, “Hipoacusia neurosensorial bilateral,” Google LLC, Mountain View, CA, 2025. [Online]. Available: https://www.google.com/search?q=hipoacusia+neurosensorial+bilateral+imagen.
[3] Top Doctors, “Déficit vestibular – Reeducación vestibular,” Top Doctors SL, Spain, 2025. [Online]. Available: https://www.topdoctors.es/articulos-medicos/la-reeducacion-vestibular-vertigo-e-inestabilidad/.

[4]World Health Organization (WHO), “Blindness and Visual Impairment – Fact Sheet,” World Health Organization, Geneva, 2024. [Online]. Available: https://www.who.int/es/news-room/fact-sheets/detail/blindness-and-visual-impairment

[5]Consejo Nacional para la Integración de la Persona con Discapacidad (CONADIS), “Se registran 801 mil personas con discapacidad visual en todo el Perú,” Gobierno del Perú, 2024. [Online]. Available: https://www.gob.pe/institucion/conadis/noticias/22052-se-registran-801-mil-personas-con-discapacidad-visual-en-todo-el-peru

[6] U.S. Patent US12133582B1, Smart cane for a visually impaired individual, 2024.
[7] U.S. Patent Application US20210369545A1, Method and system for smart navigation for the visually impaired, 2021.
[8] World Intellectual Property Organization, Patent WO2022131891A1, Haptic cane device, 2022.
[9] U.S. Patent US10900788B2, Wearable sensory belt system, 2021.
[10] MIT App Inventor, “MIT App Inventor,” Massachusetts Institute of Technology, Cambridge, MA, 2025. [Online]. Available: https://appinventor.mit.edu/
[11] EasyEDA, “EasyEDA Online Circuit Design,” EasyEDA Inc., 2025. [Online]. Available: https://easyeda.com/
[12] GPSTEC, “Botón de pánico – alerta.jpg,” GPSTEC Argentina, 2015. [Online]. Available: http://www.gpstec.com.ar/wp-content/uploads/2015/04/boton-de-panico-alerta.jpg
[13] Lucidchart, “Lucidchart – Diagramming Application,” Lucid Software Inc., South Jordan, UT, 2025. [Online]. Available: https://www.lucidchart.com/

# Slide extra: Limitaciones

Duración de la batería | Entre 2 a 3h vibrando constantemente y unas 4 si no llega a detectar nada por grandes periodos de tiempo
Visión limitada | por el mismo planteamiento solo compara el terreno en 3 direcciones, a futuro con sensores de mayor rango se espera poder abarcar un mayor rango
El botón de emergencia aún requiere participación del paciente | El SMS aún no se envia automaticamente
Aún ocupa mucho espacio | Por el planteamiento actual del proyecto no es posible reducir su tamaño pero se espera volverlo un aditamento discreto para cualquier baston

# Slide extra: Pruebas y testeos


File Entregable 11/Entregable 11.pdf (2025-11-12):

## Verificación de diseño: (Integración Hardware - Software -Manufactura Digital)

## 1. Software

Funcionalidad | Cumplimiento
La app se conecta automáticamente al dispositivo ESP32-SOS mediante Bluetooth BLE. | Aún falta probar con los componentes
en físico
Detecta la señal de alerta (SOS) enviada desde el botón físico del ESP32. | Aún falta probar con los componentes
en físico
Obtiene la ubicación actual del usuario utilizando el GPS del celular. | Aún falta probar con los componentes
en físico
Genera un enlace de Google Maps con las coordenadas actuales. | Aún falta probar con los componentes
en físico
Envía un mensaje SMS con el texto “ALERTA SOS” y el enlace de ubicación al número de emergencia configurado. | Aún falta probar con los componentes
en físico
Muestra mensajes de estado (“Escaneando…”, “Conectando…”, “SOS enviado…”) en pantalla. | Aún falta probar con los componentes
en físico

Evita envíos repetidos con una función de espera
(cooldown).
| Aún falta probar con los componentes
en físico
Permite realizar una prueba manual del envío SOS con un botón virtual. | Aún falta probar con los componentes
en físico

Funciona sin conexión a internet (envío de SMS
directo).
| Aún falta probar con los componentes
en físico
Solicita y usa solo los permisos necesarios (ubicación y SMS). | Aún falta probar con los componentes
en físico

## 2. Hardware

❖ ¿Cuánto peso debe tener el dispositivo ?
Alrededor de 500g
❖ ¿Cuánto es el tiempo que debe durar la batería de forma autónoma? Entre minimo 4h
❖ ¿Con cuantos botones físicos debe contar el dispositivo?

### 2 botones fisico en la parte superior

❖ ¿Qué dimensiones debe tener el dispositivo?
100-125cm baston
❖ ¿Es removible?
Si es capaz de ser fijado y removido a voluntad

Requerimiento de diseño | Resultado del test
Alrededor de 250g | En su suma todos los componentes pesan alrededor de 330 g
Debe haber una autonomía de mínima de 4h | Duración de 5h
Debe contar con 2 botones físicos | El prototipo cuenta con 2 botones físicos el switch de encendido apagado y un botón para la señal de emergencia
Debe ser capaz de ser fijado y removido a cualquier tipo de bastón | Es capaz de ser fijado y removido mediante tornillos

## 3. Manufactura Digital:

Requerimiento del diseño | Cumplimiento
El case debe permitir la instalación de 4 sensores ultrasónicos en la cara inferior, orientados al suelo. | Los sensores se instalan correctamente; detectan desniveles y obstáculos en pruebas con maqueta.
Debe permitir el ingreso de una batería de 9 V, un ESP32 y una mini protoboard. | Las piezas se alojan correctamente dentro del case sin interferencias.
El sistema debe disponer de un mecanismo de acople al bastón. | Se logró la fijación al bastón sin juego lateral ni desplazamientos.
El diseño debe ser resistente y ligero para no añadir peso excesivo al bastón. | Peso total (case + electrónica): ≈ 200 g, dentro del rango cómodo para usuarios.
El dispositivo debe tener una autonomía mínima de 1 hora de uso continuo. | Prueba real: duración promedio 2.8–3.1 horas, dependiendo del modo Bluetooth.
Debe contar con botón SOS para activar llamada vía Bluetooth en AppInventor. | En pruebas, el celular recibe la alerta y ejecuta llamada a contacto de emergencia.
Debe permitir soportar pequeñas vibraciones y golpes (caminar con el bastón). | El case no presenta fisuras ni suelta componentes bajo uso moderado.

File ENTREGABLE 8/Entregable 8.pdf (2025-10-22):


Modelos 3D:
Aruino UNO

https://cad.onshape.com/documents/a9cb909675f1fde261f52c29/w/a461d1722f8de3f63cd49a65/e/c6438bbc33da355c75834d00 (https://cad.onshape.com/documents/a9cb909675f1fde261f52c29/w/a461d1722f8de3f63cd49a65/e/c6438bbc33da355c75834d00)

Sensor ultrasónico HC-SR04

https://cad.onshape.com/documents/4a3fbf907f4c447290f873f1/w/c2d5322ac74fb6da7c3bb4a0/e/316b95fa7f4ede136b2f01c2 (https://cad.onshape.com/documents/4a3fbf907f4c447290f873f1/w/c2d5322ac74fb6da7c3bb4a0/e/316b95fa7f4ede136b2f01c2)


Vibration module

https://cad.onshape.com/documents/4a3fbf907f4c447290f873f1/w/c2d5322ac74fb6da7c3bb4a0/e/473ae7984edc5fa917bdac37 (https://cad.onshape.com/documents/4a3fbf907f4c447290f873f1/w/c2d5322ac74fb6da7c3bb4a0/e/473ae7984edc5fa917bdac37)

Protoboard https://cad.onshape.com/documents/4a3fbf907f4c447290f873f1/w/c2d5322ac74fb6da7c3bb4a0/e/f2eff3f0cd98e1bc2c9302a6 (https://cad.onshape.com/documents/4a3fbf907f4c447290f873f1/w/c2d5322ac74fb6da7c3bb4a0/e/f2eff3f0cd98e1bc2c9302a6)

Case preliminar


https://cad.onshape.com/documents/4a3fbf907f4c447290f873f1/w/c2d5322ac74fb6da7c3bb4a0/e/f69bfc684fbe932f442388b3 (https://cad.onshape.com/documents/4a3fbf907f4c447290f873f1/w/c2d5322ac74fb6da7c3bb4a0/e/f69bfc684fbe932f442388b3)

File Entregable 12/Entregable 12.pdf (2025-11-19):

## Plan de usabilidad basado en evidencias

Sección del plan | ¿Qué es? | ¿Qué hacer? | ¿Qué evidencia deben incluir?


1. Contexto de uso | El usuario usará su bastón verde como siempre solo que ahora con el sistema integrado SENSO FLEX, lo que le permitirá tener más autonomía al momento de salir a caminar por la calle. | Paciente varón de 23 años con síndrome de Charge con problemas sensoriales y de movilidad. El paciente necesita un entorno sin irregularidades en el terreno (baches, huecos) y con supervisión casi siempre de una persona de confianza.
2. Perfil del usuario | Usuario con problemas de marcha y estabilidad. Capaz de sostener un bastón verde sin dificultad | Analizar si el paciente es capaz de detectar la señal de alerta de SENSO-LINK. | Presenta síndrome de CHARGE con hipoacusia, baja visión y alteraciones del equilibrio que limitan su orientación espacial. Requiere apoyo para la marcha y estabilidad, aunque mantiene fuerza y motricidad funcional en miembros superiores. Conserva capacidad cognitiva adecuada, comprensión verbal y disposición al aprendizaje mediante estímulos táctiles y repetitivos.
3. Análisis de tareas | Verificar si se encajo correctamente los componentes del sistema en el bastón. Conectar el bluetooth. Asegurarse que la batería está renovada. | Localizar el bastón - > verificar que el sistema esté completo antes de salir -> prender el sistema -> sostener y usar el bastón con normalidad -> realizar actividades diaria con seguridad | Realiza tareas básicas con apoyo, pero requiere supervisión al colocarse la pechera y usar el bastón. Las tareas críticas son la sincronización del sistema y el mantenimiento del equilibrio, ya que un fallo puede causar caídas o desorientación por su baja visión y alteración motora. El terapeuta recomienda entrenamiento guiado y práctica en entornos seguros.
4. Criterios de éxito (requisitos de | El paciente puede caminar sin | ¿El dispositivo mejora el equilibrio o reduce los | Verificar que el sistema este colocado correctamente <

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
rvisió

n

p

o

r
m

á

s lu

g

a

r

e

s. El pacient
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
el b

a

s

t

ó

n. t

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
al sis

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
El u

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
o in

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
el u

s

o

?

1

min Caíd

a

s

o in

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
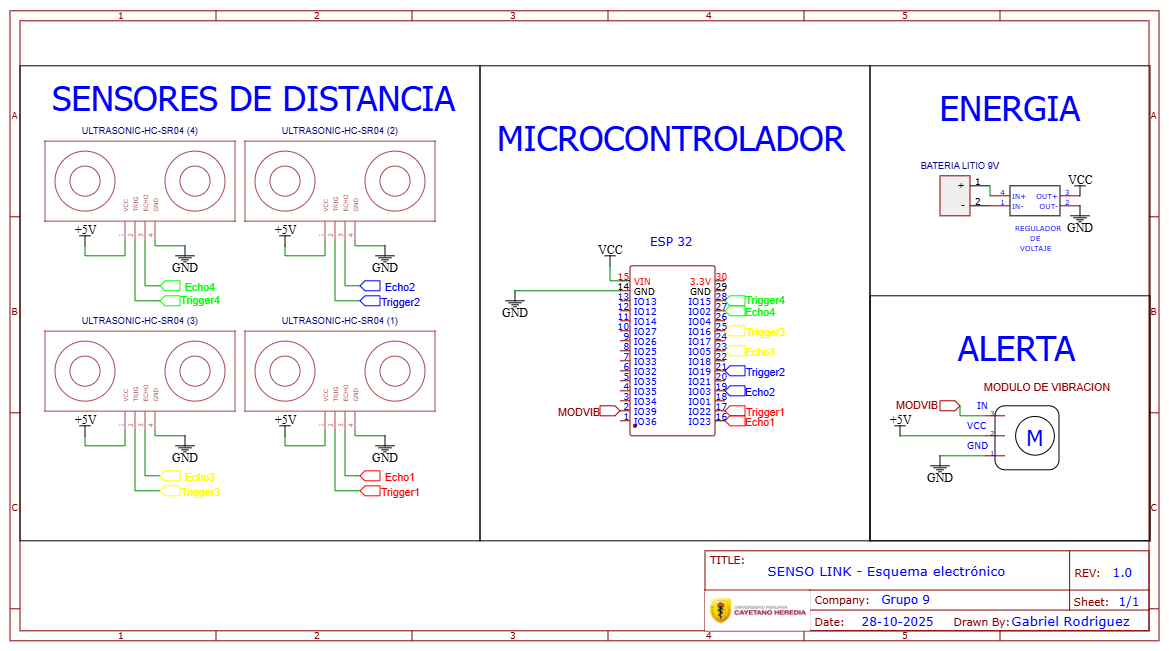
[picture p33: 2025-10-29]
Entregable_9/Schematic_Esquema-electrónico-SENSO-LINK-grupo-9_2025-10-28.png

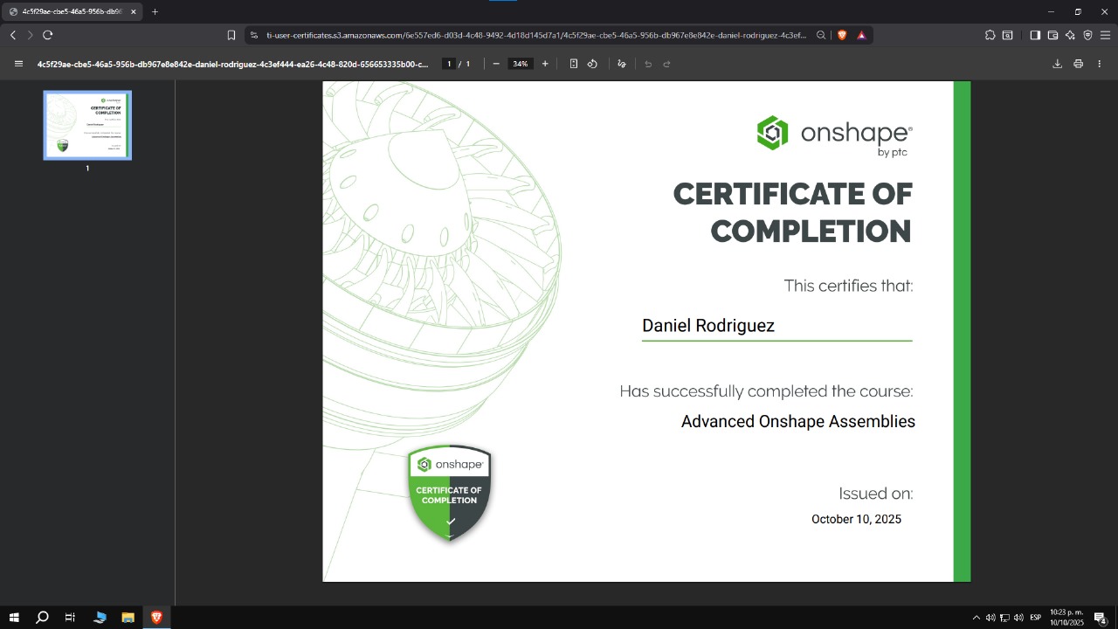
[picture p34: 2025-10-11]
Talleres2/Daniel Rodríguez/Imagen de WhatsApp 2025-10-10 a las 22.24.02_5eee3d15.jpg

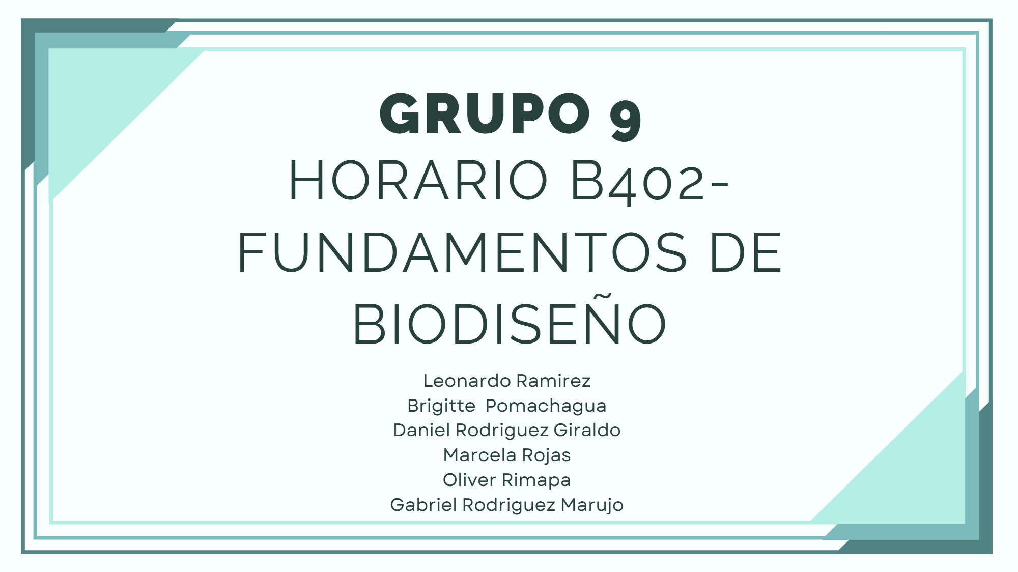
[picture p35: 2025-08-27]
Imágenes/caratula.png

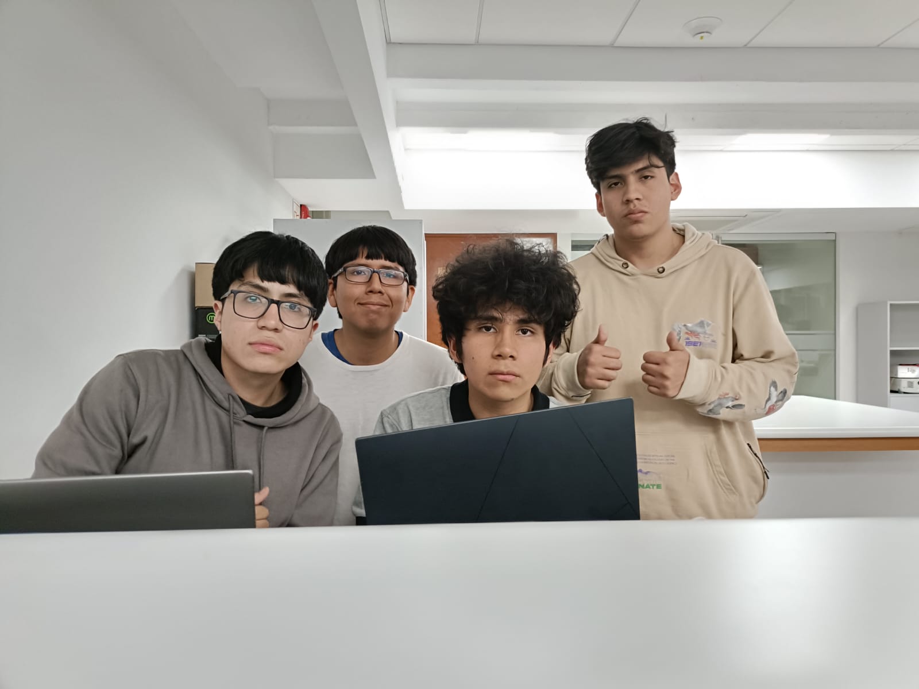
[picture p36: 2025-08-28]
FOTOS/images_md_image_7.png

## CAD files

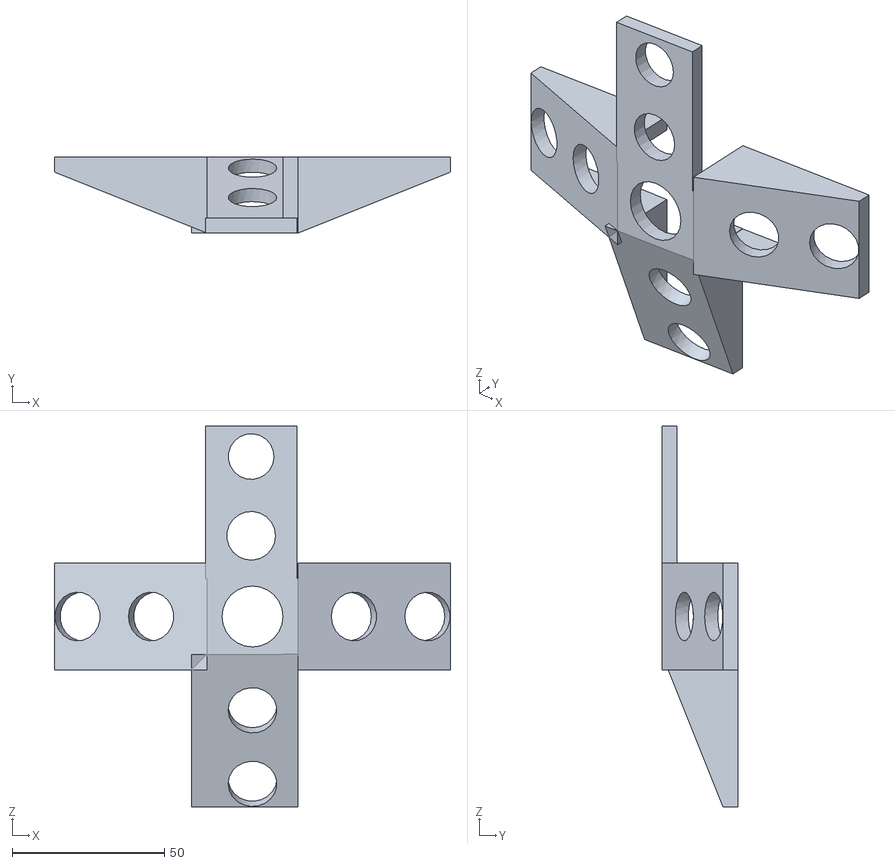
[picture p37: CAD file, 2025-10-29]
Entregable_9/Piezastl.stl
130.0 x 25.1 x 125.0

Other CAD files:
Entregable_9/piezap.stp

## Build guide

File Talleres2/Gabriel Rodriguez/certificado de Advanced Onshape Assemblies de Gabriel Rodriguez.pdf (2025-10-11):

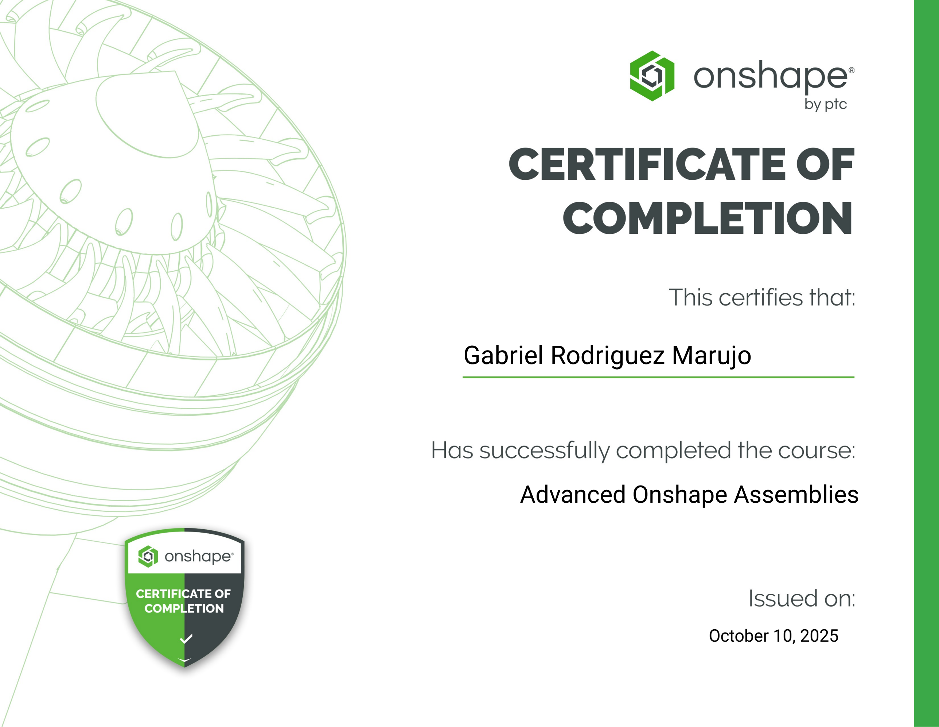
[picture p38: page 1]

Gabriel Rodriguez Marujo

Advanced Onshape Assemblies

October 10, 2025

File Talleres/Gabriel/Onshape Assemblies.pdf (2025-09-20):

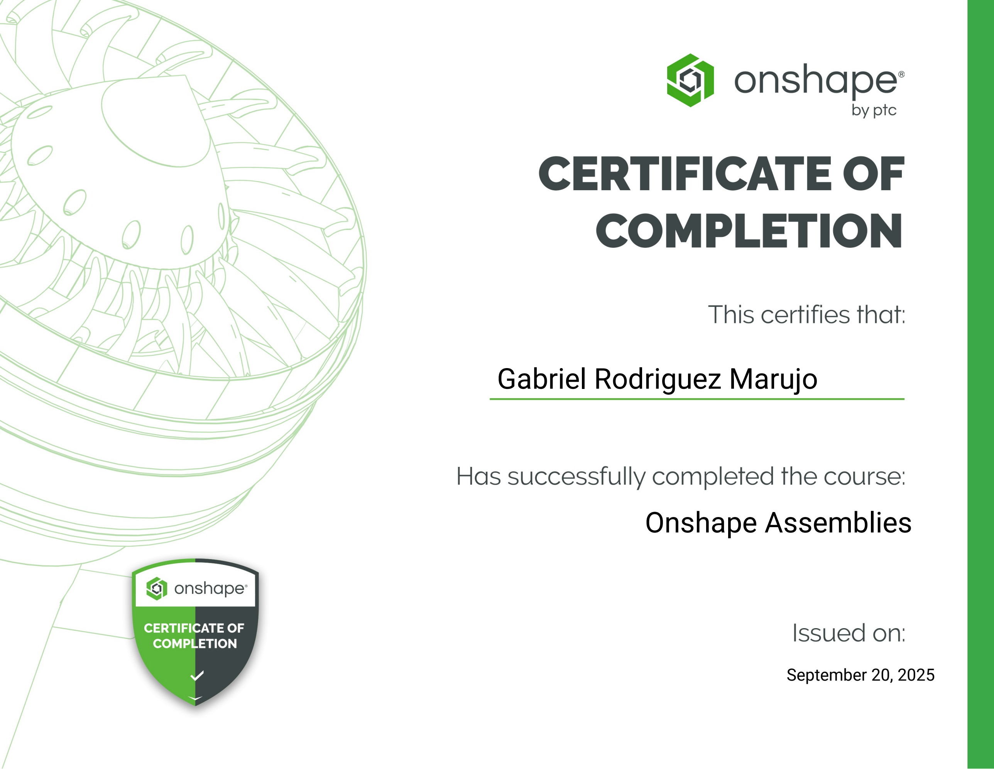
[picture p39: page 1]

Gabriel Rodriguez Marujo

September 20, 2025

Onshape Assemblies

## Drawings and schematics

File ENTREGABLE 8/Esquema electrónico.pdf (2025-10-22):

# MICROCONTROLADOR

SENSORES DE DISTANCIA | ENERGIA

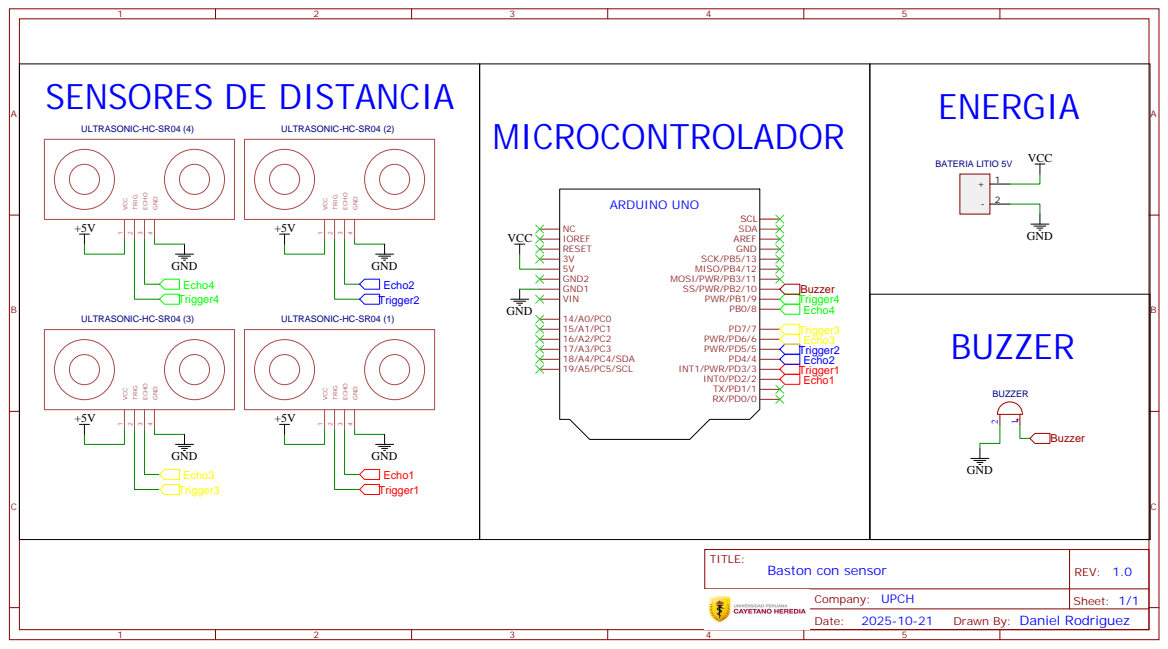
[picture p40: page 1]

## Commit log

2025-09-24 Create Entregable 5 - Análisis de patentes
2025-09-24 /Entregable 5 - Revisión de patentes
